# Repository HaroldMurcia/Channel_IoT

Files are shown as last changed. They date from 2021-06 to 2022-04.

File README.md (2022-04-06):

# Channel_IoT
<p align='left'>
    
    
</p>

# **Índice**   
- 1 [INSTALACION DE HERRAMIENTAS](#id1)
  - 1.1 [MPLABX](#id2)
  - 1.2 [Instalación de **MPLAB X** en Ubuntu](#id3)
  - 1.3 [Instalación del compilador XC8 en ubuntu ](#id4)
  - 1.4 [Instalación de MPLAB CODE CONFIGURATOR MCC ](#id5)
  - 1.5 [LoRa Development Suite](#id6)
- 2 [HARDWARE](#id7)
  - 2.1 [Documentos relacionados ](#id8) 
  - 2.2 [Requerimientos de hardware](#id9)
  - 2.3 [Enlaces de interés](#id10)
- 3 [Diseño de schematic y PCB en Eagle](#id11)
  - 3.1 [Estructura de la PCB](#id12)
  - 3.2 [PCB  Botton y Top](#id13)
  - 3.3 [Modelo PCB en 3D](#id14)
- 4 [Errores de diseño](#id36)
- 5 [Comandos modulo RN2903](#id15)
   - 5.1 [Comandos radio ](#id16)
     - 5.1.1 [Comandos para inicializar el radio **modulación LoRa**](#id17)
     - 5.1.2 [Comandos de transmisión](#id18)
     - 5.1.3 [Comandos de recepción](#id19) 
- 6 [Protocolo serial ](#id21)
  - 6.1 [Tablas de contenido del mensaje](#id22)
    - 5.1.1 [Cabecera del mensaje](#id23)
    - 5.1.2 [Tabla de familia](#id24)
    - 5.1.2 [Descripción tablas](#id25)
- 7 [Documentación de código](#id26)
-  6.1 [Versiones de software](#id27)
    - 7.1.1 [Programación en PIC18Lf45k50](#id28)
    - 7.1.2 [Programación en dsPIC30F4011](#id29)
    - 7.1.2 [Interfaz nodo maestro](#id30)
- 8 [Resultados](#id31)
  - 8.1 [Apertura de compuerta](#id32)
  - 8.2 [Distancia del sensor de ultrasonido](#id33)
  - 8.3 [Alimentación de la board](#id34)
  - 8.4 [Temperatura de la board](#id35)

# INSTALACION DE HERRAMIENTAS  
## MPLABX  
Este algoritmo se ha realizado en [Mplab x IDE](https://www.microchip.com/en-us/development-tools-tools-and-software/mplab-x-ide) Versión 5.50 en el compilador [XC8]( https://www.microchip.com/en-us/development-tools-tools-and-software/mplab-xc-compilers) versión 2.32. A su vez se usó el plugin MCC [MPLAB® Code Configurator]( https://www.microchip.com/en-us/development-tools-tools-and-software/embedded-software-center/mplab-code-configurator) el cual esta disponible para windows linux y mac, este ayuda a generar las librerías básicas del micro controlador, cabe aclarar que la familia dspic30 no tiene soporte en este plugin.

## Instalación de **MPLAB X** en Ubuntu  
Primero se verifica la arquitectura de sistema, para ello abrimos una terminal y ejecutamos el siguiente comando:
```
uname - m
```
uname -m

Se mira si la distribución de Linux tiene soporté de multi arquitectura en el caso de no tenerlo se debe instalar una librería especial
```
dpkg --print-foreign-architectures
```
arquitectura

Entonces aquí se observa que nos devuelve i386 lo que quiere decir que, si es multi arquitectura, ahora antes de seguir con el proceso se debe verificar que no haya actualizaciones del sistema 
```
sudo apt-get update
```
Ahora lo que se debe hacer es instalar las librerías para que **MPLAB**  sea compatible con instrucciones de procesador de 32bits
```
sudo apt-get install libc6:i386 libx11-6:i386 libxext6:i386 libstdc++6:i386 libexpat1:i386
```
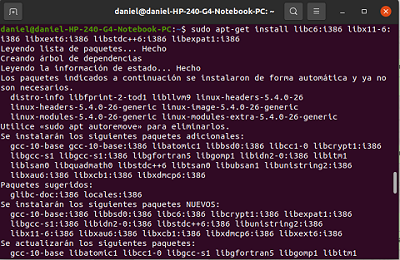
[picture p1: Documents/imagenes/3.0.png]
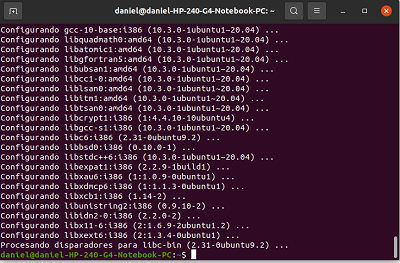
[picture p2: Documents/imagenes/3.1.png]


Ahora se busca la  página oficial de microchip para descargar [MPLAB X IDE]( https://www.microchip.com/en-us/development-tools-tools-and-software/mplab-x-ide) en la sección de **Downloads, Documentation and Other Resources**
Después de haber descargado el software, nos dirigimos a la carpeta en la que se descargo
```
cd descargas/
```
Para la instalación del software, se descomprime el archivo y se convierte el archivo descargado a ejecutable  
```
tar -xvf MPLABX-v5.50-linux-installer.tar
chmod u+x MPLABX-v5.50-linux-installer.sh
```
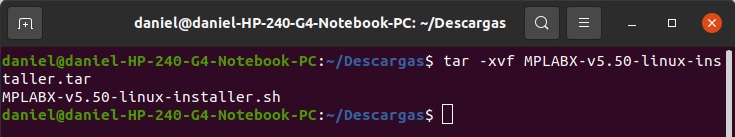
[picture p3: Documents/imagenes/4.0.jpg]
descomprime

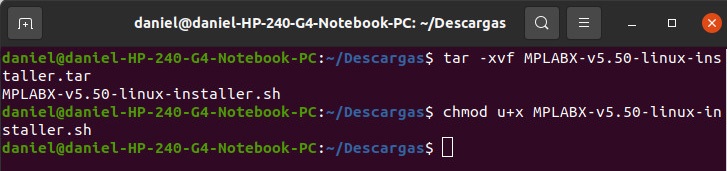
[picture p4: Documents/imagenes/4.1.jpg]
ejecutable


Ejecutar el instalador 
```
sudo ./MPLABX-v5.50-linux-installer.sh
```
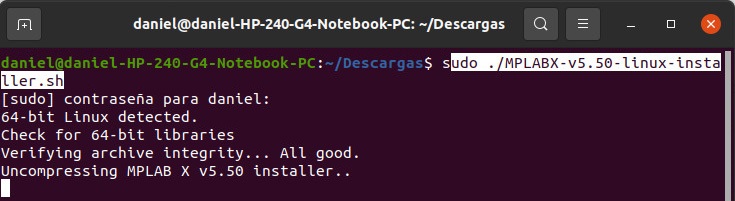
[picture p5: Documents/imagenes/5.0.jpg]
intalador


A continuación, se muestra las partes mas importantes del instalador 

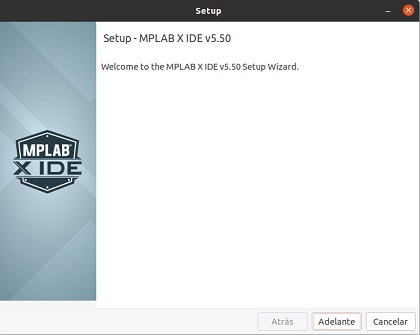
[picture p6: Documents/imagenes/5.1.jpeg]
ventana1

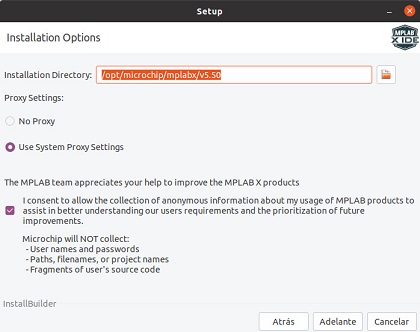
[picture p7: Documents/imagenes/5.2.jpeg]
ventana2

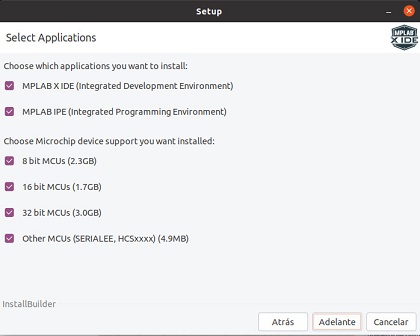
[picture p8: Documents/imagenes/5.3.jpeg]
ventana3


Al final de la instalación se debe reiniciar el PC para completar el proceso de instalación 

## Instalación del compilador XC8 en ubuntu  
Ahora es necesario instalar el compilador para el microcontrolador que desee trabajar 8bits,16bits y 32bits [MPLAB XC]( https://www.microchip.com/en-us/development-tools-tools-and-software/mplab-xc-compilers) sección **Downloads, Documentation and Other Resources** y **compiler dowloads**

Después de haber descargado la aplicación, vamos a la carpeta en la que lo guardamos y lo volvemos un ejecutable y lo ejecutamos 
```
chmod u+x xc8-v2.32-full-install-linux-x64-installer.run
sudo ./xc8-v2.32-full-install-linux-x64-installer.run
```
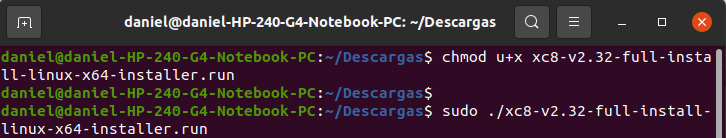
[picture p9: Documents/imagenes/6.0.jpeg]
xc8


Se deja todo por defecto y next

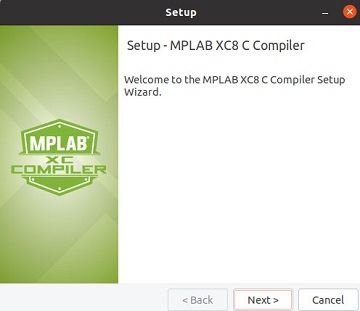
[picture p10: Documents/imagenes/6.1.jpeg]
ventana4


Al final de la instalación se debe reiniciar el PC para completar el proceso de instalación

## Instalación de MPLAB CODE CONFIGURATOR MCC  
Cabe aclarar que MCC es solamente compatible con la ultima versión de MPLAB X y esta disponible para todos los sistemas operativos. Además el procesos se realizo en ubuntu, sin embargo es el mismo proceso para Windows y MAC os.

MCC es un plugin que permite configurar algunos microcontroladores de una manera rápida y sencilla, ya que este genera una interfaz en la que se puede configurar una serie de parámetros, utilizar algunas librerías y este genera código de la librería según los parámetros estipulados  para comenzar a trabajar en el proyecto.

**Nota: MCC no es compatible con la familia DSPIC30**

* Abrir la aplicación de MPLAB X IDE
* Tools
* plugins
* Available Plugins
* Y buscamos MPLAB Code Configurator 
* Pulsar en install

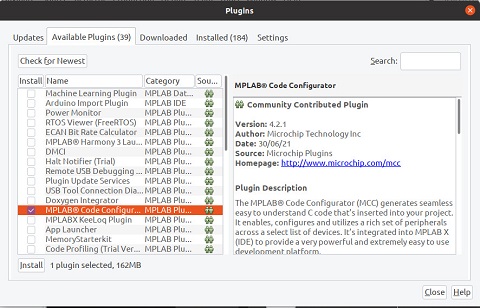
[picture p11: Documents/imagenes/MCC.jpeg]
MCC
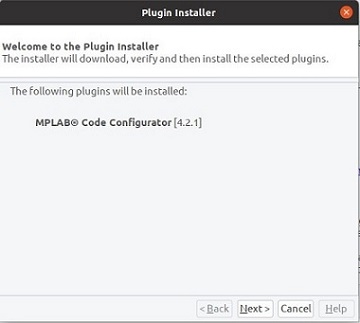
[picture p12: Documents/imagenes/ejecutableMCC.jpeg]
EJECUTABLEMCC
  
 
Al final de la instalación se escoge reset now, y se reinicia MPLAB X después aparecerá de la siguiente manera, “si no se ha creado ningún proyecto”

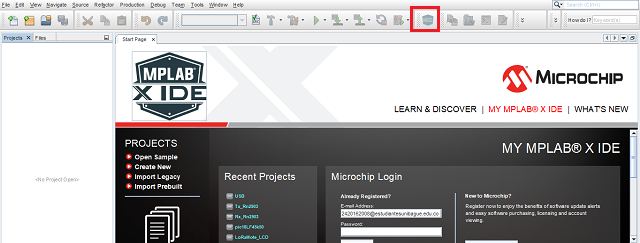
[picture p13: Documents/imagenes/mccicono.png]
MCCicono


## LoRa Development Suite  
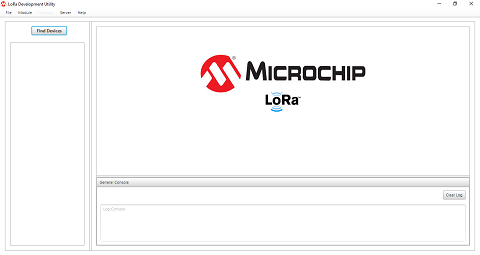
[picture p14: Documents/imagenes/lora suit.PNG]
lora suit


Es una interfaz grafica que permite la configuración de los diferentes comandos que implementa modulo RN2903 y RN2483, de esta manera el usuario aprenda como debe enviar los datos de manera serial sin muchas complicaciones, **cabe aclarar que esta interfaz no es estrictamente necesaria para configurar el módulo RN2903,ya que es una guía, de igual forma, los comandos se pueden enviar mediarte el UART programndo el  microcontrolador** para más información  mirar la guía de comandos del [módulo RN2903]( https://ww1.microchip.com/downloads/en/DeviceDoc/RN2903%20LoRa%20Technology%20Module%20Command%20Reference%20User%20Guide-40001811B.pdf)

### instalación
Esta aplicación esta disponible para todos los sistemas operativos y se puede encontrar en la [pagina oficial de microchip]( https://www.microchip.com/wwwproducts/en/RN2903), en el apartado de **Documents**, **software libreires/firmware** se encuentran las aplicaciones, solo basta con abrir la aplicación darle next y **mirar la ruta de la carpeta en la que se va instalar ya que se debe ir a buscar la ampliación a ese  directorio** esto es para el caso de Windows. Ir al siguiente enlace en caso de [Linux
]( https://www.gaggl.com/2018/04/microchip-lorawan-development-utility-on-ubuntu/)

### RN2903 ACTUALIZAR FIREWARE
El siguiente video tiene como objetivo explicar la forma de actualizar el firmware del modulo RN2903 de la tarjeta LoRa Mote, dado el caso de que se allá borrado el firmware del módulo RN2903 [Video en youtube](https://youtu.be/kyjtmIkalMk)

# HARDWARE  
Este repositorio tiene como objetivo mostrar  los elementos que componen el sistema y su configuración en con construcción de esta, es decir la asignación de pines o conexiones de los dispositivos entre si.

## Documentos relacionados  
* [Configuración o asignación de pines](https://docs.google.com/spreadsheets/d/19cve4B_YzyOGqIv9DEK3eCqArvopMfsAZXm61Hay0jQ/edit?usp=sharing)
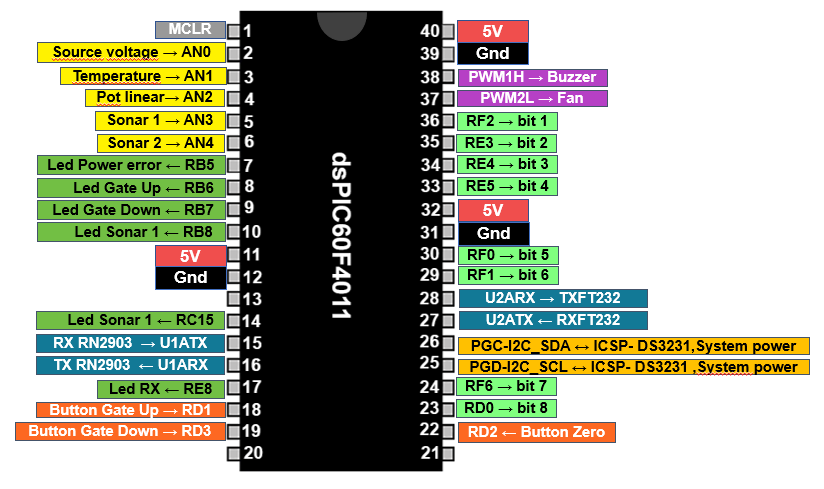
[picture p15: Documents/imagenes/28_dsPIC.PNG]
Resumen de pindes

* [Google Drive](https://drive.google.com/drive/folders/19VFRMTp_xo8fuAuP7UYOIrlyNO1dNOWd?usp=sharing)
* [Diagrama de bloques](https://drive.google.com/file/d/1_osPgyQmuKj5nIkt5gdU3hPU3BZLeOLT/view?usp=sharing)
* [Schematic](https://github.com/HaroldMurcia/Channel_IoT/blob/master/Eagle/schematic.pdf)

## Requerimientos de hardware  
A continuación se muestran los componentes principales que encabezan el sistema, los demás dispositivos se encuentran en [Datasheet]( https://github.com/HaroldMurcia/Channel_IoT/tree/master/Hardware/Datasheet)
* [MaxSonar](https://co.mouser.com/ProductDetail/DFRobot/SEN0272?qs=T8HDo%252BTk69VWj8BEbH%252BU3Q%3D%3D)
* [LoRa Mote](https://www.microchip.com/Developmenttools/ProductDetails/dm164139)
* [Microchip RN2903](https://www.microchip.com/wwwproducts/en/RN2903)
* [Dspic30f4011](https://www.microchip.com/wwwproducts/en/dsPIC30F4011)

## Enlaces de interés  
* [Platformio](https://platformio.org/)
* [RAdioHead](https://www.airspayce.com/mikem/arduino/RadioHead/)

# Diseño de schematic y PCB en Eagle  
[Cotización de los componentes](https://docs.google.com/spreadsheets/d/1AnpxCE8uhZ4Mzhw6TfTGnhGRriO4N8LUufEemXK9A1I/edit#gid=807096094) En este link se entra la cotización de los diferentes componentes usados en la PCB exceptuando la tarjeta LoRa mote, Dspic, Tblocks y buzzer, dicha cotización se realizo para armar 3 tarjetas, mas adelante se describe  de manera superficial la función del componente.

## Estructura de la  PCB  
En el siguiente [enlace](https://docs.google.com/spreadsheets/d/1AnpxCE8uhZ4Mzhw6TfTGnhGRriO4N8LUufEemXK9A1I/edit#gid=1786186541) se encontrarán la distribución de los pines del DSpic para realizar las diferentes conexiones, este archivo contiene el número del pin, así como el label del esquemático de Eagle su tipo de puerto, es decir si es ADC, Digital etc.

La siguiente imagen muestra la distribución de cada uno de los componentes usados para la Pcb, estos componentes tienen su letra y numero correspondiente o identificador del componente, además de su valor si este lo requiere, cada  uno de los componentes se situó de manera estratégica, de tal manera que sea fácil soldar y acceder a este; de igual forma cada elemento esta lo más cerca posible a la conexión con otros dispositivos con los que se interconecta con el fin de tener la menor resistencia posible en la pista que los interconecta. 
La siguiente [tabla](https://docs.google.com/spreadsheets/d/1AnpxCE8uhZ4Mzhw6TfTGnhGRriO4N8LUufEemXK9A1I/edit#gid=1117524344) muestra la descripción mas detallada de cada elemento de la PCB.

Como se puede evidenciar la pcb diseñada es doble capa y cuenta con dos tamaños de anchura, cada uno de estos tamaños fueron calculados por medio de la norma IPS2221, estos cálculos se hicieron por medio de una calculadora que ofrece [Digikey]( https://www.digikey.com/es/resources/conversion-calculators/conversion-calculator-pcb-trace-width) para ello se busco en el datasheet de cada unos de los componentes las corrientes nominales, el consumo de cada uno de los componentes es bajo y en ancho de la pista es muy pequeño, por tanto por requerimientos mínimos que exigen algunas empresas para la fabricación de las pcb para  cada pista debe ser de 0.2mm, para este diseño se tomo un valor por arriba que es de 0.254mm, por otra parte para el calculo de las pistas de potencia se sumo la corriente nominal de todos los componentes, esto se hizo buscado el peor de los casos, lo cual hace suponer que todos los componentes están encendidos en el mismo momento. La corriente total fue alrededor de 1.3A, por tanto el anchor de la pista es de 0.55mm, sin embargo se sobre dimensiono un poco ya que algunos dispositivos pueden tener picos de corriente que muchas veces  no se especifica en el datasheet por tanto el ancho es de 1.016mm, por ultimo para realizar el cálculo se escogió una temperatura ambiente de 25°C y el aumento de temperatura de 30°C el espesor de 1oz/ft^2. 
[Tabla de cosumo y calculos de ruteo](https://docs.google.com/spreadsheets/d/1AnpxCE8uhZ4Mzhw6TfTGnhGRriO4N8LUufEemXK9A1I/edit#gid=618312286)

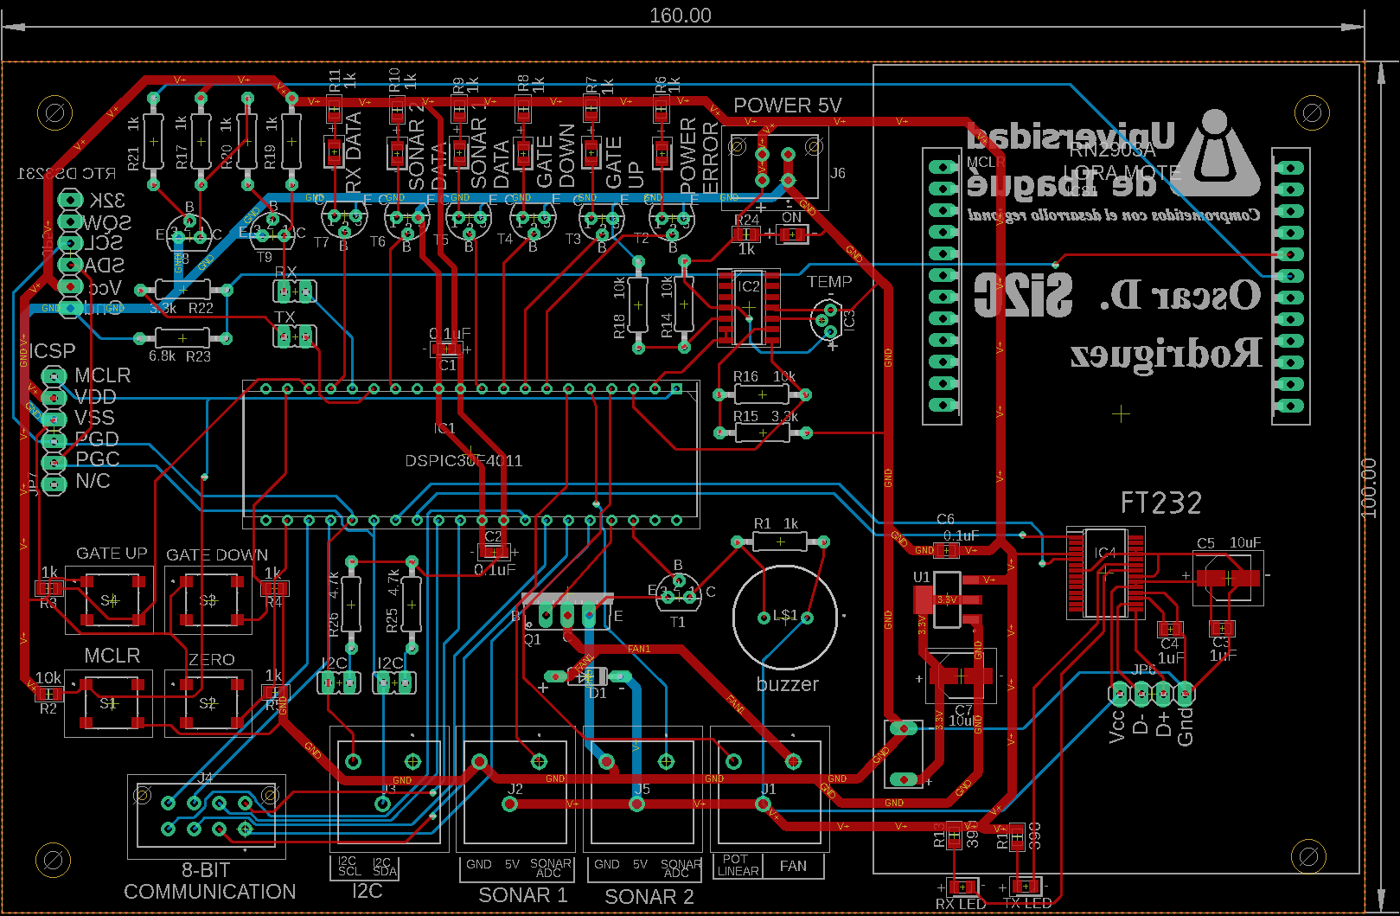
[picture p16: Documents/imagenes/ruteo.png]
PCB ruteo

## PCB  Caras Botton Y Top  

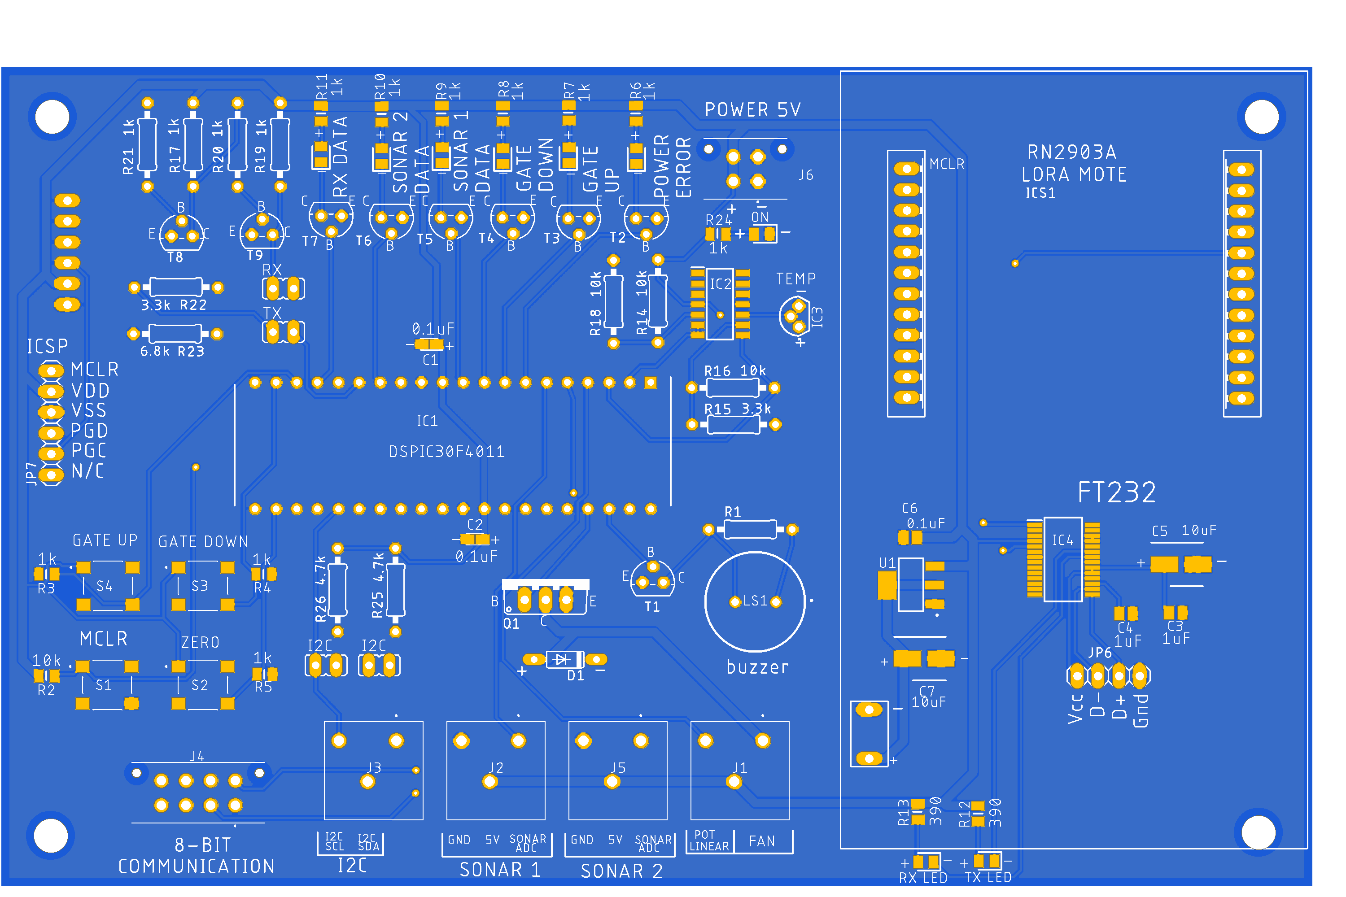
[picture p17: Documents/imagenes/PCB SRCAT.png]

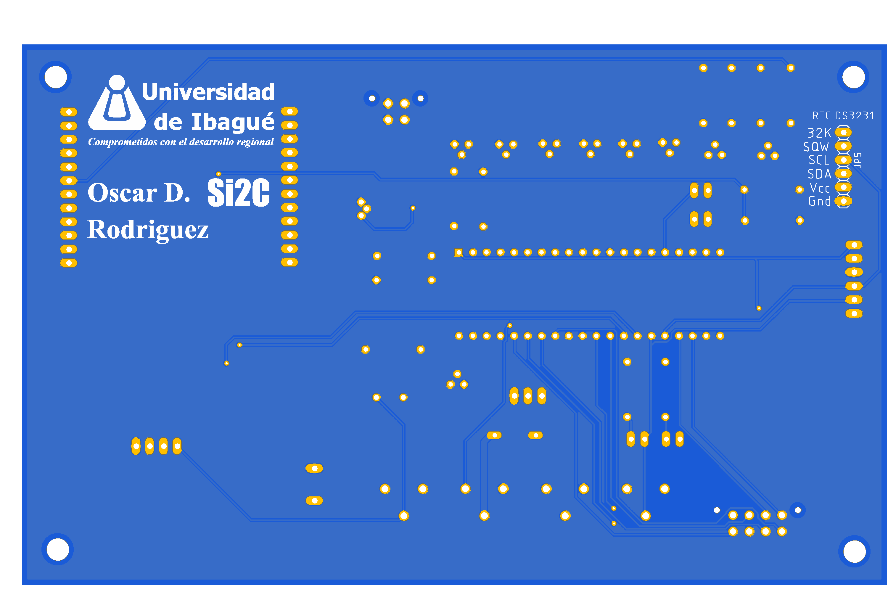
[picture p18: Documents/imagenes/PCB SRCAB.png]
PCB BOTTOM


## Modelo PCB en 3D 
La Pcb cuenta con diferentes componentes, la alimentación cuenta con un conector molex de 4 pines, el cual tiene una sola forma de conectar, por otra parte los indicadores visuales y audibles son indicadores del estado en que se encuentran el sistema, por otra parte el microcontrolador es que se encargara de procesar los diferentes sensores, procesamiento de datos y envió de datos al LoRa, por otra parte los sensores se leen mediante ADC, el bloque de comunicación de sistema de potencia se usa para comunicar un sistema de potencia que se encarga de abrir o cerrar la compuerta, los botones de calibración sirven para abrir o cerrar la compuerta calibrar la altura de sensores sonar, por último se dejó un puerto para programar el microcontrolador con un pickit mediante ICSP.
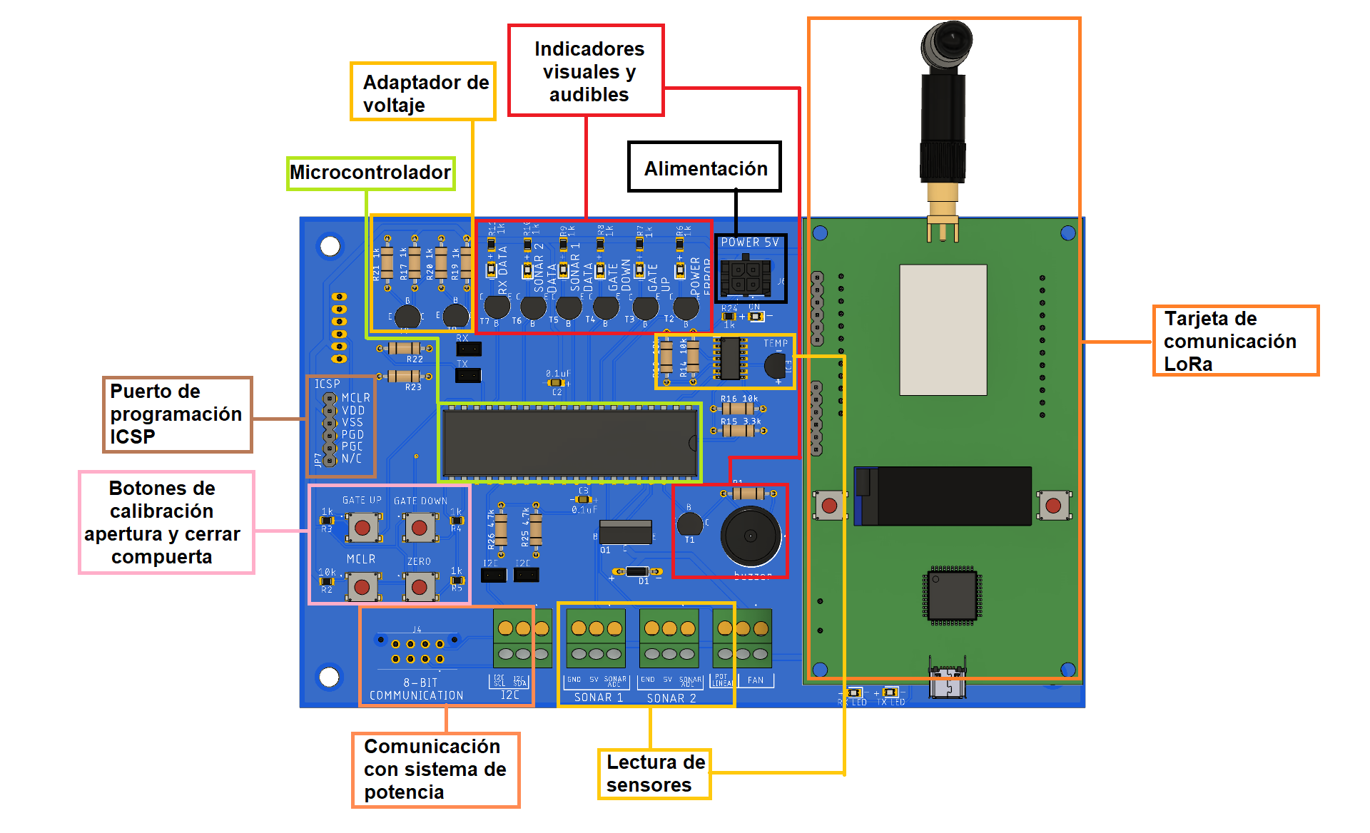
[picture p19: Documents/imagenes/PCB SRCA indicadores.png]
PCB SRCA indicadores


[Modelo en fusion360](https://a360.co/3zkWzcB)
Clave: 159753
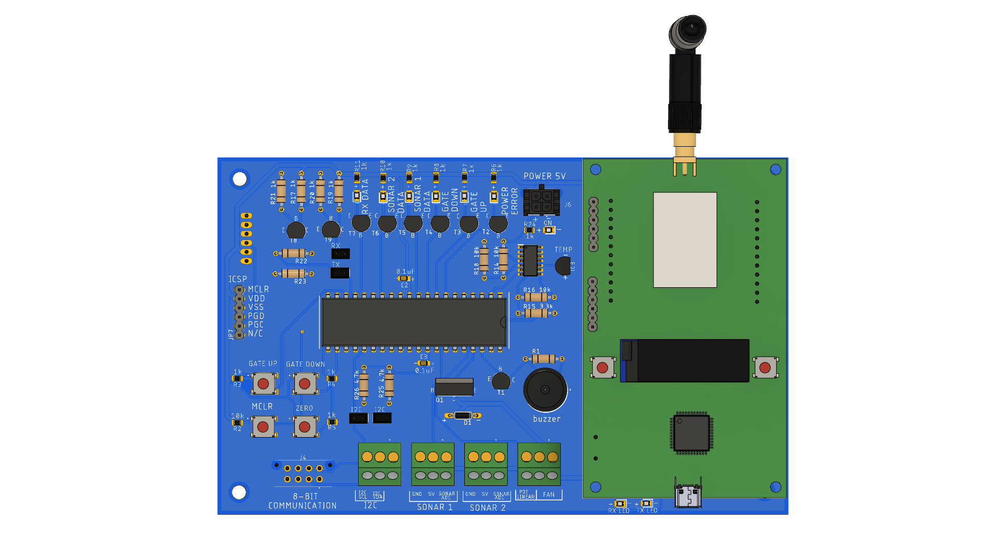
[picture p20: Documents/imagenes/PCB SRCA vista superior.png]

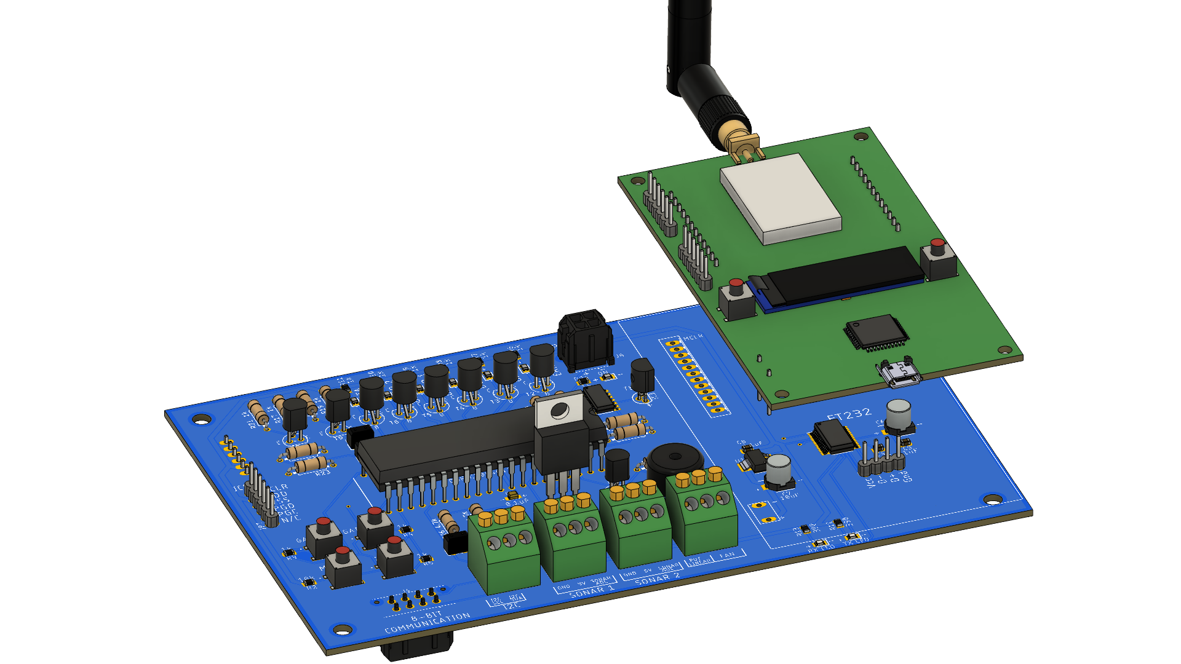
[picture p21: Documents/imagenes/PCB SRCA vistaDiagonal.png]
PCB TOP DIAGOANL

# Errores de diseño 
- El primer error se encuentra en la parte de los pulsadores, las pistas para soldar cada pulsador son muy cortas, por tanto se deben dejar con mayor longitud a la actual, con el fin de que el pulsador se pueda soldar con mayor facilidad.
- cuando se construyeron las librerías del ADC, en la hoja de datos de la familia dsPIC30f se especifica que se deben conectar los pines 40 y 39 a la alimentación para la referencia del ADC, no obstante, la hoja de datos del dsPIC30f4011 especificaba que los pines eran usados para colocar un voltaje entre 2.7 y 5V, con lo anterior, se colocaron dos cables entre la base del dsPIC y el MCU, para poder leer las señales análogicas provenientes de los sensores.

# Comandos modulo RN2903
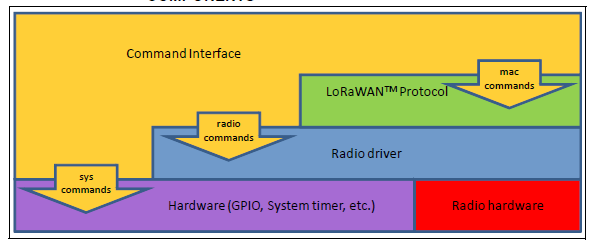
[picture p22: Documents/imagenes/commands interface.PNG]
commands interface


El modulo RN2903 tiene una gran cantidad de comandos, sin embargo solo se deben usar una cabecera para la comunicación ya sea **mac o radio**, en esta sección se implementaron los comandos radio, estos facilitan la comunicación entre dos módulos RN2903.

Por otra parte, los comandos en general se deben enviar con la misma cantidad de espacios que especifica la hoja de datos, a su vez al final de cada comando se de enviar retorno de carro **CR** y salto de línea **LF** .

## Comandos radio

### Comandos para inicializar el radio **modulación LoRa**

1. El siguiente comando permite cambiar el método de modulación utilizado por el módulo.
Además, la modificación del modo de funcionamiento no afecta los parámetros, variables o
registros previamente configurados. Así mismo, el comando es muy simple ya que solamente
decide si es LoRa o FSK. En este documento se trabaja los comandos relacionados con LoRa.
```http
  radio set mod <mode>
```
| Parametro | Comando  | Parametro |Description parametro | Tipo de respuesta |
| :--- | :--- | :--- |:--- | :---|
| `radio set` |  `mod` | `<mode>` |**String**. lora o fsk |  ok o invalid_param  |

`Ejemplo` 
```http
  radio set mod lora\r\n
```
2. El siguiente comando determina la potencia de salida del transceptor. La cual se puede
ajustar por encima del límite especificado, este ajuste de potencia permite compensar algunas
pérdidas en el cable o línea de transmisión en dBm. El valor máximo que puede alcanzar es
de 17 dBm a 20 dBm
```http
  radio set pwr <pwrOut>
```
| Parametro | Comando  | Parametro |Description parametro | Tipo de respuesta |
| :--- | :--- | :--- |:--- | :---|
| `radio set` |  `pwr` | `<pwrOut>`  |**Decimal**. de 2 hasta 20 |  ok o invalid_param  |

`Ejemplo` 
```http
   radio set pwr 3\r\n 
```
3. Este comando establece el ancho de banda de radio para el funcionamiento de LoRa,
ambos dispositivos deben tener el mismo ancho de banda, puesto que, ambos dispositivos se
comportan como transmisor y receptor 
```http
  radio set bw <bandWidth>
```
| Parametro | Comando  | Parametro |Description parametro | Tipo de respuesta |
| :--- | :--- | :--- |:--- | :---|
| `radio set` |  `bw` | `<bandWidth>`  |**Decimal**. puede ser de 125,250,500 en KHz |  ok o invalid_param  |

`Ejemplo` 
```http
   radio set bw 250\r\n 
```
4. El comando crc permite activar o desactivar la detección de errores, CRC Cyclic Redun-
dancy Check este comando se usa para detectar errores o cambios accidentales en datos
sin procesar. Por tanto, si el detector de errores encuentra irregularidades en los mensajes
automáticamente los eliminará del sistema
```http
  radio set crc < crcHeader >
```
| Parametro | Comando  | Parametro |Description parametro | Tipo de respuesta |
| :--- | :--- | :--- |:--- | :---|
| `radio set` |  `crc` | `<crcHeader>`  |**String**. puede ser on o off |  ok o invalid_param  |

`Ejemplo` 
```http
   radio set crc on\r\n
```
5. El siguiente comando permite configurar la tasa de codificación de errores. Esto significa
que cada 4 bits útiles se codificarán con 5, 6, 7 u 8 bits transmitidos según su valor.
```http
  radio set cr <codingRate>
```
| Parametro | Comando  | Parametro |Description parametro | Tipo de respuesta |
| :--- | :--- | :--- |:--- | :---|
| `radio set` |  `cr` | `<codingRate>`  |**String**. puede ser 4/5,4/6, 4/7, 4/8.|  ok o invalid_param  |

`Ejemplo` 
```http
   radio set cr 4/5\r\n
``` 
6. El siguiente comando permite configurar la frecuencia de operación del transmisor y
receptor. Cabe añadir que el transmisor y receptor deben estar sintonizados a la misma
frecuencia, si no se cumple, no habrá comunicación entre los dispositivos.
```http
  radio set freq <frequency>
```
| Parametro | Comando  | Parametro |Description parametro | Tipo de respuesta |
| :--- | :--- | :--- |:--- | :---|
| `radio set` |  `freq` | `<frequency>`  |**Decimal**. puede ser 902000000 a 928000000 en Hz|  ok o invalid_param  |

`Ejemplo` 
```http
   radio set freq 923300000\r\n
``` 
7. El siguiente comando permite   configurar la inversión IQ.
```http
  radio set iqi <iqInvert>
```
| Parametro | Comando  | Parametro |Description parametro | Tipo de respuesta |
| :--- | :--- | :--- |:--- | :---|
| `radio set` |  `iqi` | `<iqInvert>`  |**String**. puede ser on o off |  ok o invalid_param  |

`Ejemplo` 
```http
  radio set iqi off\r\n
``` 
8. El watchDog actualiza la duración del tiempo de espera (en milisegundos) del
temporizador de vigilancia aplicado al módulo. Cuando esta función está habilitada, el reloj
de vigilancia se iniciará para cada transceptor que recibe o transmite. El reloj de Watchdog
se detiene mientras una actividad está en curso. Si el parámetro de la recepción es continuo
WDT debe ser 0.
```http
  radio set wdt <watchDog>
```
| Parametro | Comando  | Parametro |Description parametro | Tipo de respuesta |
| :--- | :--- | :--- |:--- | :---|
| `radio set` |  `wdt` | `<watchDog>`  |**Decimal**. puede ser 0 a 4294967295 en milisegundos. |  ok o invalid_param  |

`Ejemplo` 
```http
  radio set wdt 15000\r\n
``` 
9. El parámetro sf permite configurar el factor de dispersión ortogonal FS, esta instrucción es
muy importante, ya que, la configuración ayuda a aumentar o disminuir el rango de alcance
que puede ser entre 5 km en zonas urbanas y 15 km en zona rural. Sin embargo,
la velocidad de transmisión de datos se ve afectada por el valor que tome SF lo que hace
que disminuya o aumente la velocidad de transmisión, es decir, que FS a mayor rango es
inversamente proporcional a la velocidad de transmisión de datos en kb/s..
```http
  radio set sf <spreadingFactor>
```
| Parametro | Comando  | Parametro |Description parametro | Tipo de respuesta |
| :--- | :--- | :--- |:--- | :---|
| `radio set` |  `sf` | `<spreadingFactor>`  |**String**. puede ser sf7, sf8, sf9, sf10, sf11 o sf12. |  ok o invalid_param  |

`Ejemplo` 
```http
  radio set sf SF12\r\n 
``` 
10. El parámetro sync configura la palabra de sincrónica para la comunicación, esta palabra
para la modulación LoRa es de 1 byte y se usa para sincronizar una transmisión de datos
indicando el final de la información del encabezado y el inicio de los datos, la cual debe ser
igual en el dispositivo que reciba la información.
```http
  radio set sync <syncWord>
```
| Parametro | Comando  | Parametro |Description parametro | Tipo de respuesta |
| :--- | :--- | :--- |:--- | :---|
| `radio set` |  `sync` | `<syncWord>`  |**Hexadecimal**. tamaño de un Byte|  ok o invalid_param  |

`Ejemplo` 
```http
  radio set sync 34\r\n 
``` 
### COMANDOS DE TRANSMISIÓN  

1. El siguiente comando pausa la funcionalidad de la pila LoRaWAN para permitir la configuración del transceptor (radio).  
Se debe llamar antes de hacer una transmisión o recepción.
```http
  mac pause
```
| Cabecera | Comando  | Description parametro | Tipo de respuesta |
| :--- | :--- | :--- | :---|
| `mac` |  `pause` |**Decimal**. 0 – 4294967295 en milisegundos |  ok o invalid_param  |

`Ejemplo` 
```http
  mac pause\r\n
```
2. El siguiente comando permite   configurar La transmisión de datos simples  
```http
  radio tx <data>
```
| Cabecera | Comando  | Parametro |Description parametro | Tipo de respuesta |
| :--- | :--- | :--- |:--- | :---|
| `radio` |  `tx` | `<data>`  |**Hexadecimal**. de 0 hasta 255  Bytes |  ok,invalid_param, busy,radio_tx_ok o radio_err  |

`Ejemplo` 
```http
   radio tx 1\r\n     
```
3. El siguiente comando reanuda la funcionalidad de la pila LoRaWAN para continuar con la funcionalidad normal después de haber sido pausado.  
Se debe realizar cuando se termina de hacer una transmisión o recepción  
```http
  mac resume
```
| Cabecera | Comando  | Description parametro | Tipo de respuesta |
| :--- | :--- | :--- | :---|
| `mac` |  `pause` |**Decimal**. 0 – 4294967295 en milisegundos |  ok o invalid_param  |

`Ejemplo` 
```http
  mac resume\r\n
```
### Comandos de Recepción   

1. El siguiente comando pausa la funcionalidad de la pila LoRaWAN para permitir la configuración del transceptor (radio).  
Se debe llamar antes de hacer una transmisión o recepción.
```http
  mac pause
```
| Cabecera | Comando  | Description parametro | Tipo de respuesta |
| :--- | :--- | :--- | :---|
| `mac` |  `pause` |**Decimal**. 0 – 4294967295 en milisegundos |  ok o invalid_param  |

`Ejemplo` 
```http
  mac pause\r\n
```
2. El siguiente comando permite   configurar La transmisión de datos simples  
```http
  radio rx <rxWindowSize>
```
| Cabecera | Comando  | Parametro |Description parametro | Tipo de respuesta |
| :--- | :--- | :--- |:--- | :---|
| `radio` |  `rx` | `<rxWindowSize>`  |**Decimal**. de 0 hasta 65525 milisegundos, 0 recepción continua |  ok,invalid_param, busy,radio_tx_ok o radio_err  |

`Ejemplo` 
```http
   radio rx 0\r\n     
```
3. El siguiente comando reanuda la funcionalidad de la pila LoRaWAN para continuar con la funcionalidad normal después de haber sido pausado.  
Se debe realizar cuando se termina de hacer una transmisión o recepción  
```http
  mac resume
```
| Cabecera | Comando  | Description parametro | Tipo de respuesta |
| :--- | :--- | :--- | :---|
| `mac` |  `pause` |**Decimal**. 0 – 4294967295 en milisegundos |  ok o invalid_param  |

`Ejemplo` 
```http
  mac resume\r\n
```

# Protocolo serial
Este es un protocolo que se implementa para hacer una comunicación entre maestro y esclavo, de manera que se pueda reconocer que se esta enviando, como llega el mensaje y que datos son los que se están enviado, a continuación, se explica como esta conformado 
## Tablas de contenido del mensaje
### Cabecera del mensaje
| star msg | ID1  | ID2 |Type of Reading | Data |end smg|
| :--- | :--- | :--- |:--- | :---| :---|
|`radio_rx `|`ID master`|`ID slave`|`Msg family`|`Data info`|`\r\n`|

### TABLA DE FAMILIA   
| ID1|ID2|Type Command  | Description |
| :--- | :--- |:--- | :---|
|`ID master` **Decimal de 0-255**|`ID slave` **Decimal de 0-255**|`0`|`Reserved`|
|`ID master` **Decimal de 0-255**|`ID slave` **Decimal de 0-255**|`1`|`Sonar H	`|
|`ID master` **Decimal de 0-255**|`ID slave` **Decimal de 0-255**|`2`|`sonar L	`|
|`ID master` **Decimal de 0-255**|`ID slave` **Decimal de 0-255**|`3`|`Temp	`|
|`ID master` **Decimal de 0-255**|`ID slave` **Decimal de 0-255**|`4`|`Power	`|
|`ID master` **Decimal de 0-255**|`ID slave` **Decimal de 0-255**|`5`|`Fecha hora	`|
|`ID master` **Decimal de 0-255**|`ID slave` **Decimal de 0-255**|`6`|`%Apertura compuerta	`|
|`ID master` **Decimal de 0-255**|`ID slave` **Decimal de 0-255**|`7`|`confirmacion	` falta definirlo|

|Type Command  | Data | Meaning |
| :--- | :--- |:---- |
|`1`|`0`| reserved	 | 
|`1`|`1-4999mm`| **sonar_on_H**| 

|Type Command  | Data | Meaning |
| :--- | :--- |:---- |
|`2`|`0`| reserved	 | 
|`2`|`1-4999mm`| **sonar_on_L**|

|Type Command  | Data | Meaning |
| :--- | :--- |:---- |
|`3`|`0`| reserved	 | 
|`3`|`1-60°c`| **read_temp**| 

|Type Command  | Data | Meaning |
| :--- | :--- |:---- |
|`4`|`0`| reserved	 | 
|`4`|`4-5V`| **power_on**| 

|Type Command  | Data | Meaning |
| :--- | :--- |:---- |
|`5`|`0`| reserved	 | 
|`5`|`hora/mes/año`| **send_datatime**| 

|Type Command  | Data | Meaning |
| :--- | :--- |:---- |
|`6`|`0`| reserved	 | 
|`6`|`%(0-100)`| **Enable_motor **| 

|Type Command  | Data | Meaning |
| :--- | :--- |:---- |
|`7`|`0`| reserved	 | 
|`7`|`1`| **send_data **| 
|`7`|`2`| **get_data  **| 

### Descripción tablas   

Como se mostró anteriormente el protocolo cuenta con diferentes tablas, de esta manera mostrar a gran escala como se conforma protocolo. Para empezar, el protocolo tiene una palabra de inicio ` star msg ` la cual viene definida por el módulo RN2903 que es: ` radio_rx` con esta se identifica donde comienza el mensaje. Las siguientes palabras del mensaje son los identificadores de las tarjetas  ` ID1 = ID master`, ` ID2 = ID slave`, estos identificadores pueden tener un valor en decimal entre  0 – 255 cada tarjeta debe tener un numero único, de tal forma que cuando se envié la información no haya más de un dispositivo recibiendo algo que no debe, estos identificadores sirven para saber con quién se está haciendo la comunicación  ` ID1 = ID master` y de donde proviene la información ` ID2 = ID slave`, además estos identificadores se usan para saber si se deben procesar la información o no ya que  hay varia tarjetas sintonizadas a la misma frecuencia.

La siguiente palabra clave del mensaje es tipo de comando `Type Command ` y este es un numero especifico, este se especifica en la **tabla de familia** en esta se muestra que significa cada valor, por otra parte, este dato le dice al que recibe el mensaje que tipo de lectura se ha enviado en el mensaje. Por ultimo las dos palabras que termina el mensaje son: datos y fin del mensaje `Data` `end smg` respectivamente. `Data` corresponde al valor de lectura de las mediciones o datos específicos que se estén enviado y `end smg` corresponde al final del mensaje, el cual esta definido por el modulo RN2903 y corresponde al retorno de carro CR y salto de línea LN \r\n 

# Documentación de código
La carpeta src contiene 4 diferentes capetas en las que se muestran diferentes códigos de manera simple a la mas compleja el manejo del dispositivo RN2903 usando una [comunicación simple]( https://github.com/HaroldMurcia/Channel_IoT/tree/master/src/Comunicacion%20basica%20MOTE%20a%20MOTE), usando una [comunicación avanzada]( https://github.com/HaroldMurcia/Channel_IoT/tree/master/src/Comunicacion%20avanzada%20Mote%20a%20Mote) usando una estructura de mensaje y por último la integración de sistema embebido construido [Nodo esclavo]( https://github.com/HaroldMurcia/Channel_IoT/tree/master/src/Nodo%20esclavo/SlaveDSpic.X). En la carpeta [InterfazNodoMaster]( https://github.com/HaroldMurcia/Channel_IoT/tree/master/src/InterfazNodoMaster) se encuentra la interfaz de nodo maestro.
## versiones de software
### Programación en PIC18Lf45k50
```http
   MPLAB X 5.45v
   XC8 compiler 2.25v
```
### Programación en dsPIC30F4011
```http
   MPLAB X 5.45v
   XC16 compiler 1.7v
```
### Interfaz nodo maestro
```http
   Python 3.9.7v
   serial 3.5v
   tkinter 8.5v
   threadign 3.8v
```
# Resultados
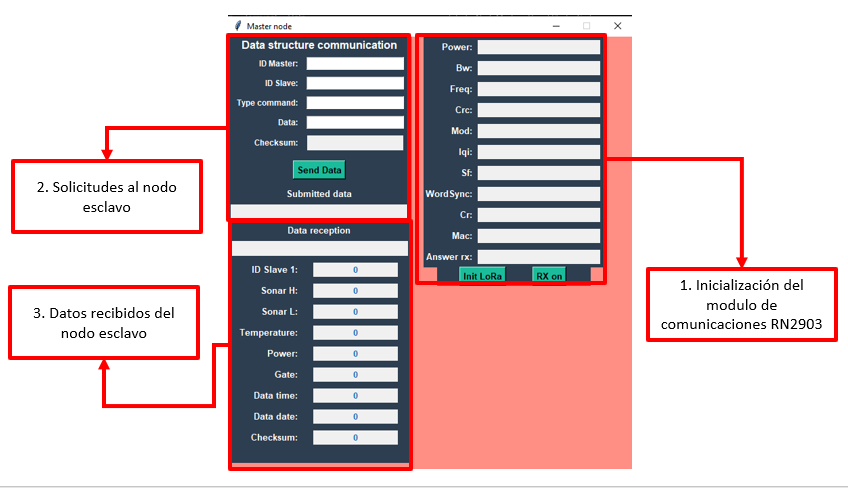
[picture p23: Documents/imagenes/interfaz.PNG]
interfaz
A continuación, se muestra la interfaz usada para la comunicación con el nodo maestro y además una serie datos representados gráficamente que fueron recolectadas en una ventana de 24 horas. 
## Apertura de compuerta
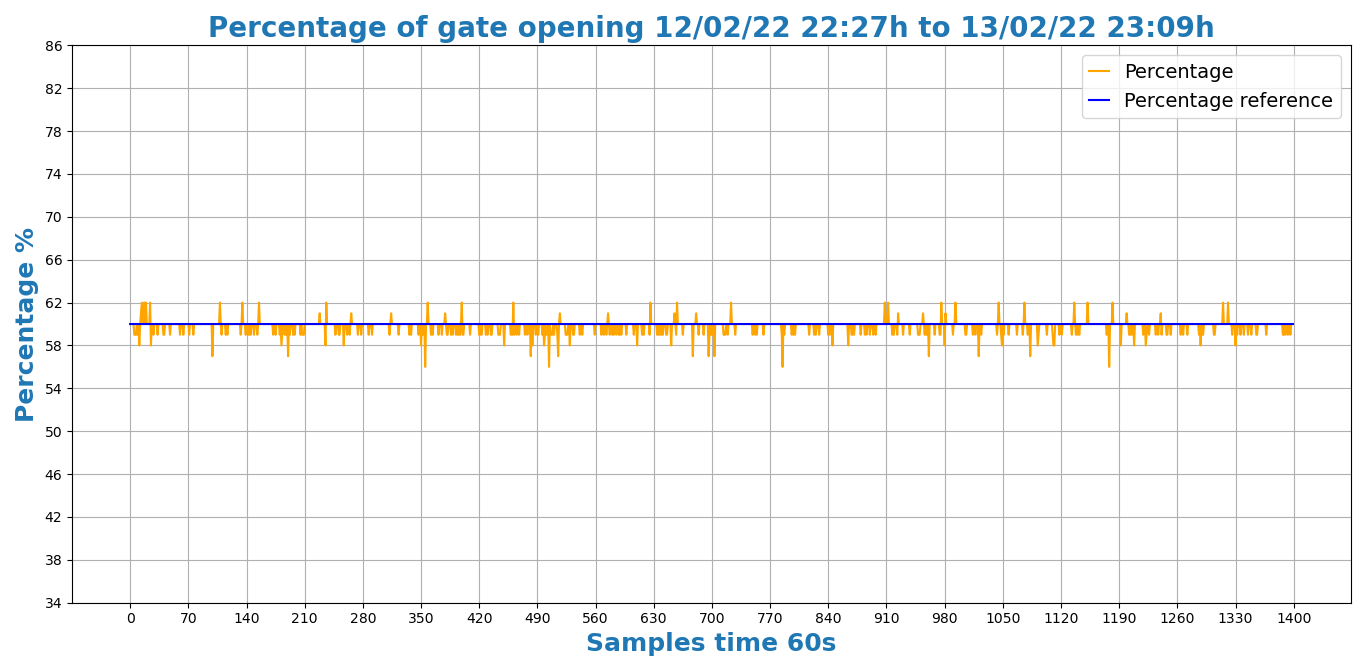
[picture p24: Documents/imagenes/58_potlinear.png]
Potecimetro

## Distancia del sensor de ultrasonido
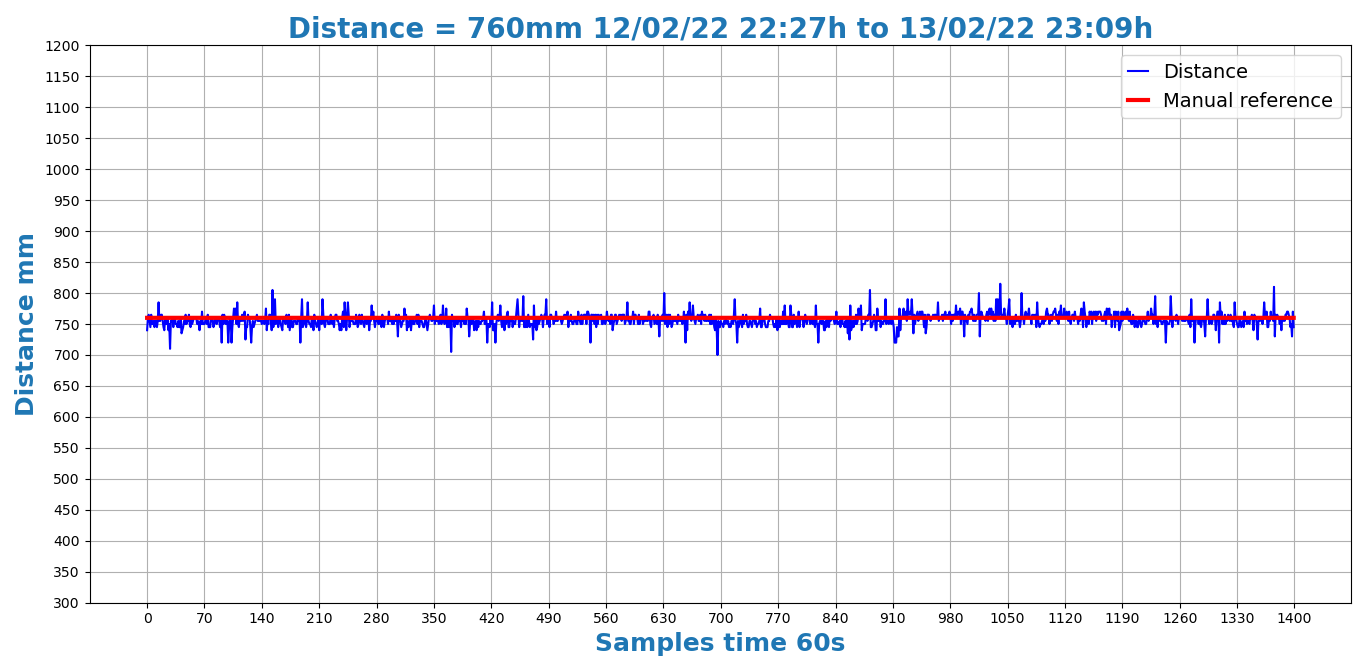
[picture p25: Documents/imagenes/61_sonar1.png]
ultrasonido

## Alimentación de la board
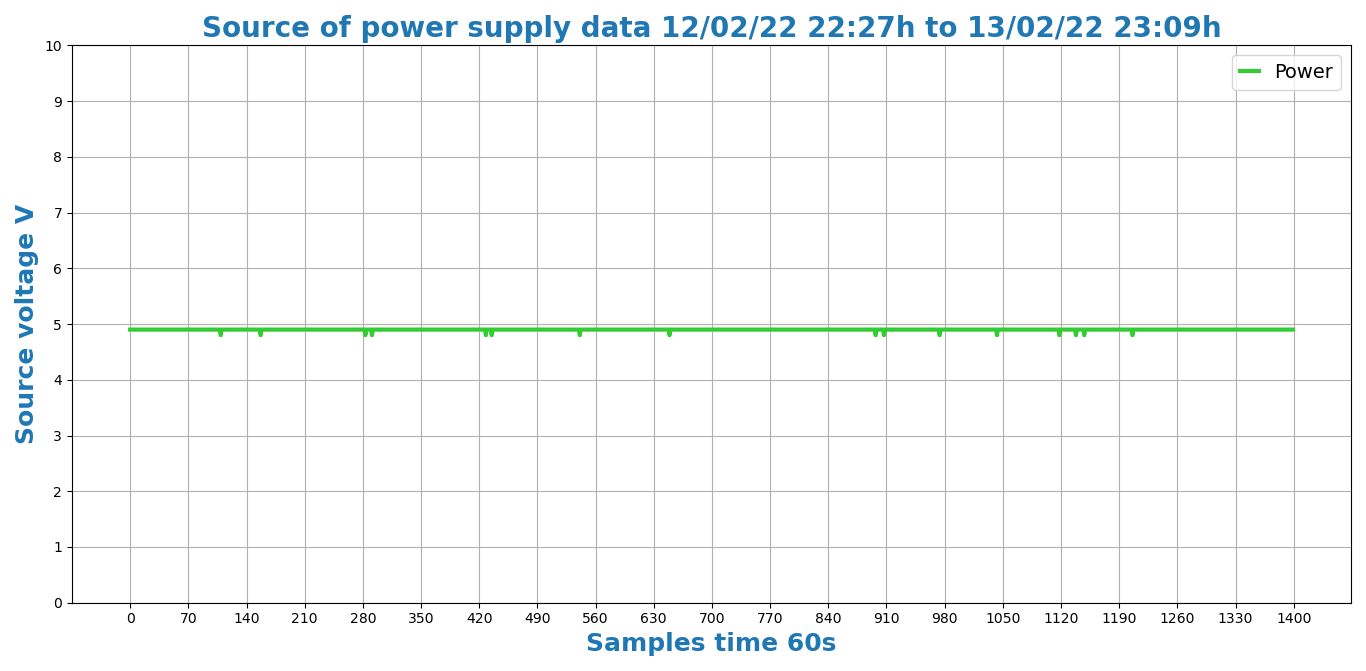
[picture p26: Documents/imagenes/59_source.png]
alimentancion

## Temperatura de la board
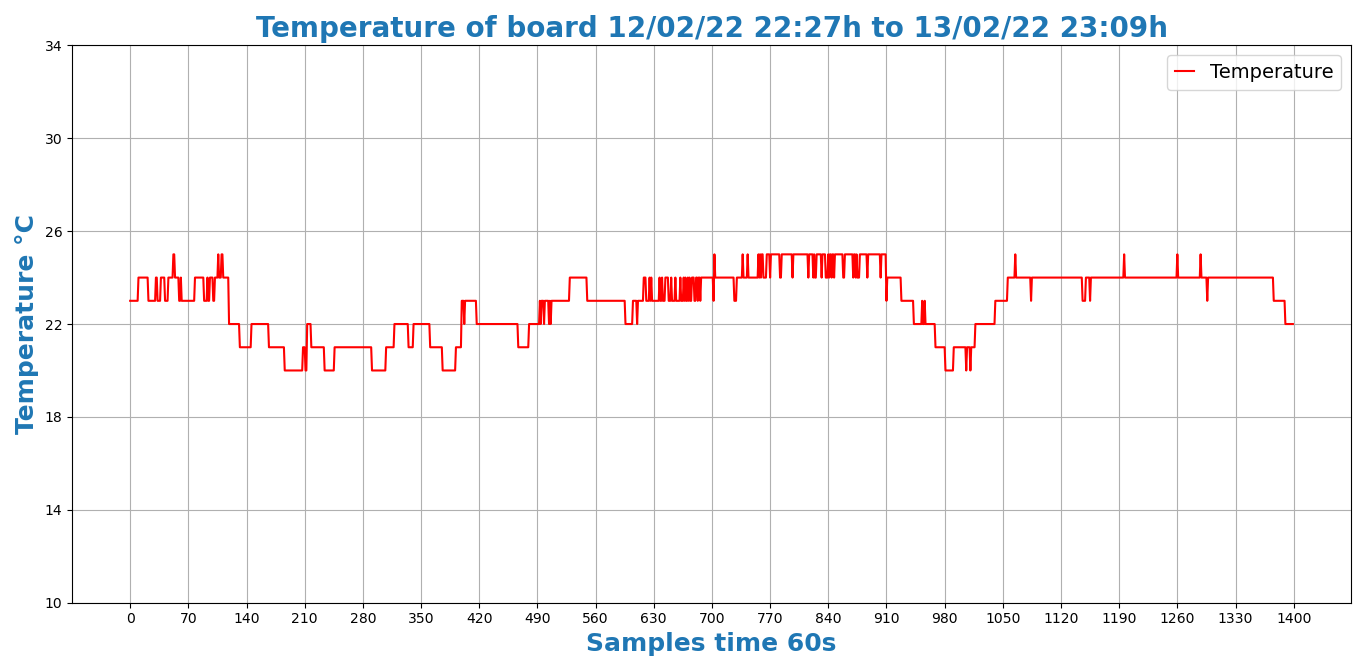
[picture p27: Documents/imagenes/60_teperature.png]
temperatura


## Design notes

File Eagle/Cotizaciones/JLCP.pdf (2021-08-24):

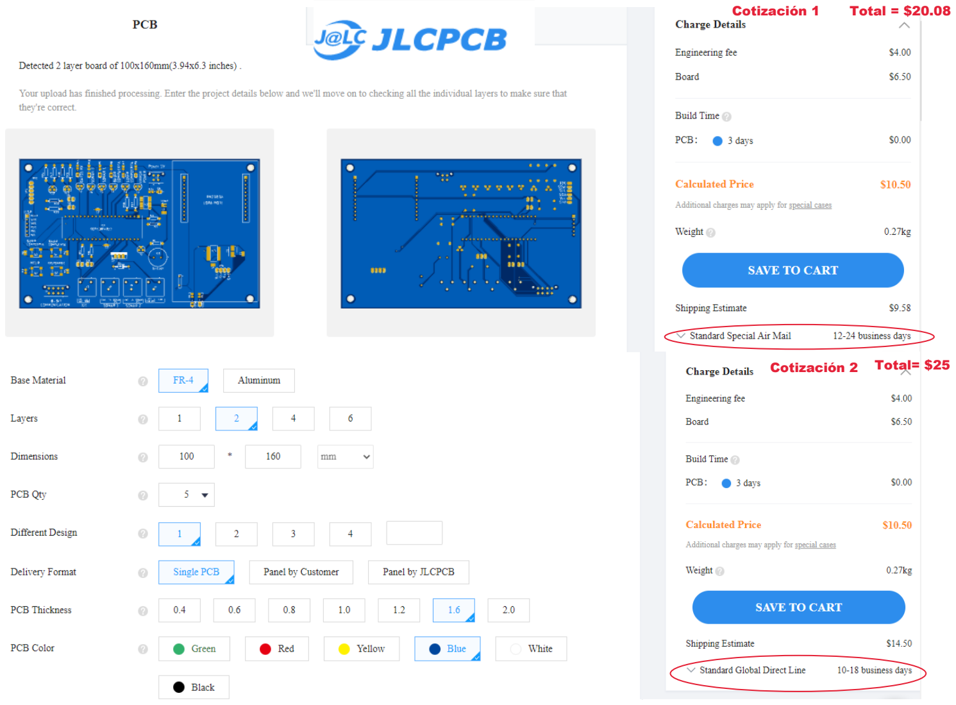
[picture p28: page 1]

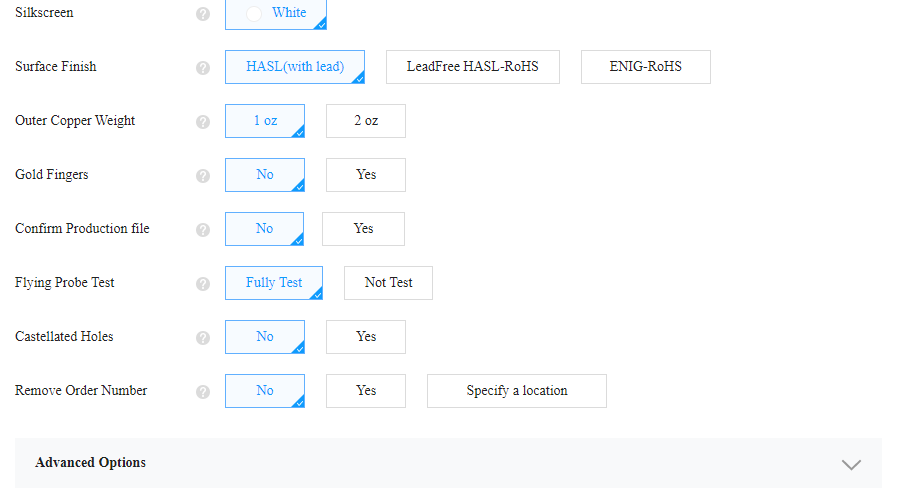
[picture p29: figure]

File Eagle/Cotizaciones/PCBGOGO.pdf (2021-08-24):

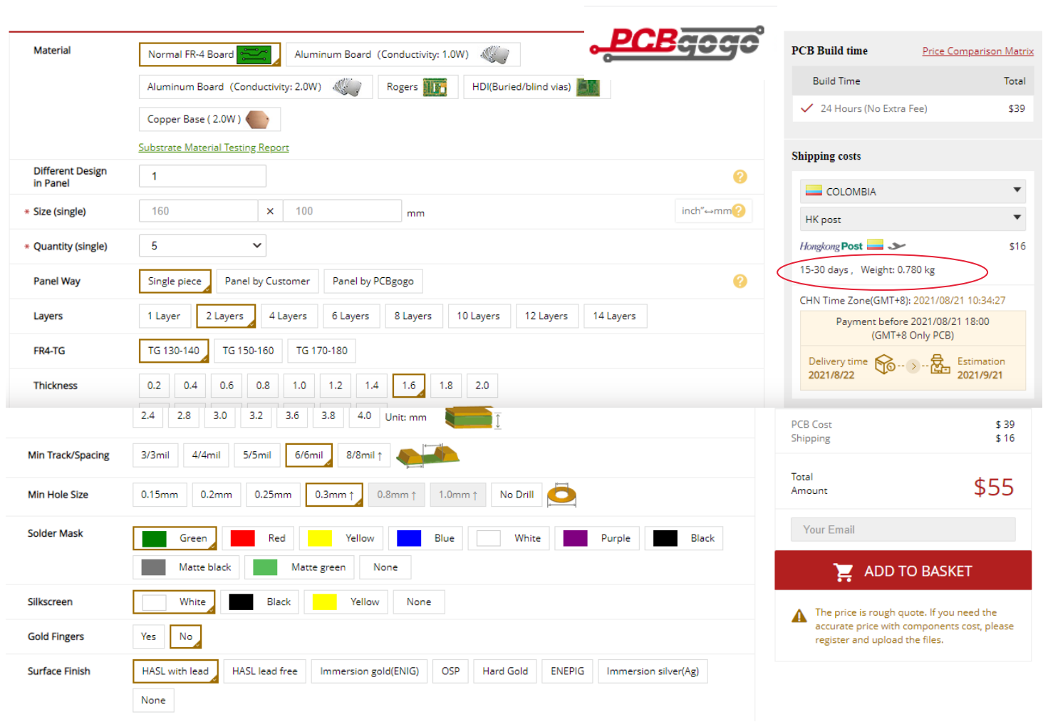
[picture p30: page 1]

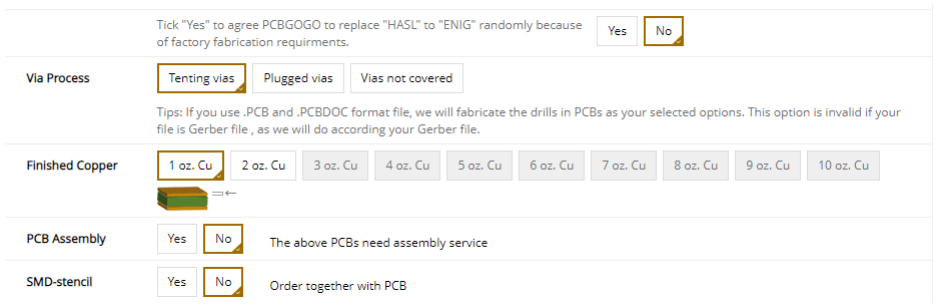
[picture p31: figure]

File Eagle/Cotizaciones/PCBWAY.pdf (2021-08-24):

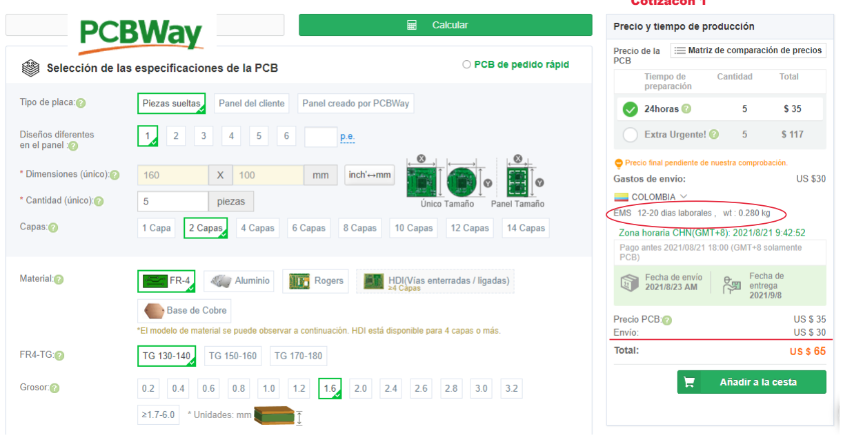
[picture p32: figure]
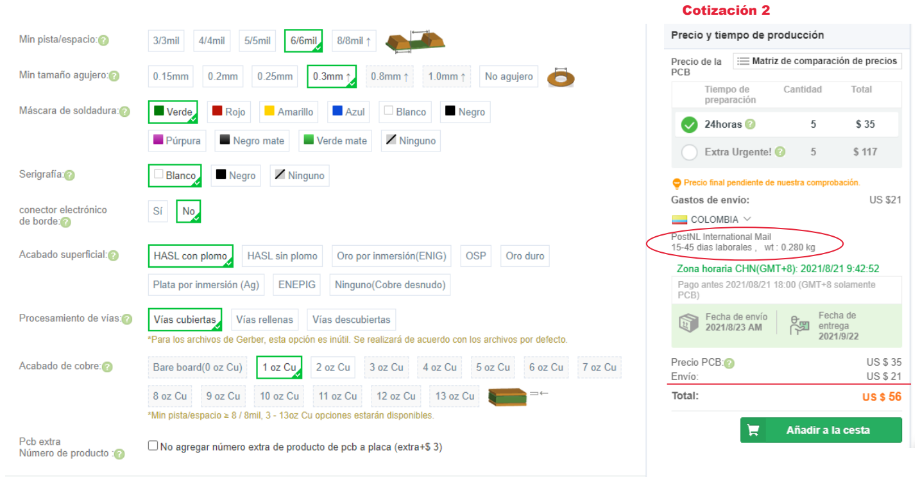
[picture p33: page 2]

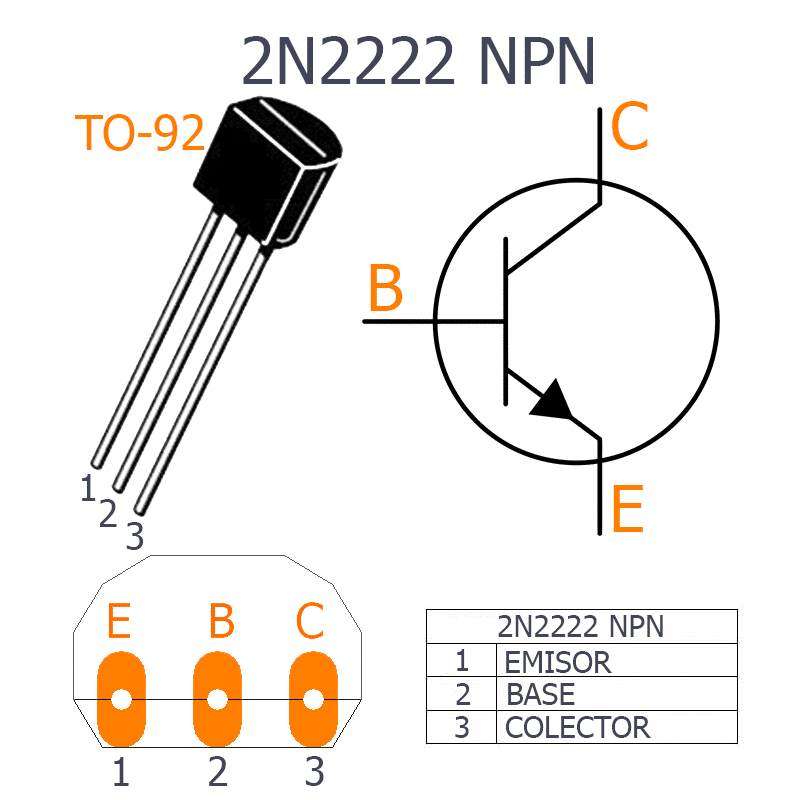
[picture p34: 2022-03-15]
Hardware/Datasheet/2N2222-NPN.png

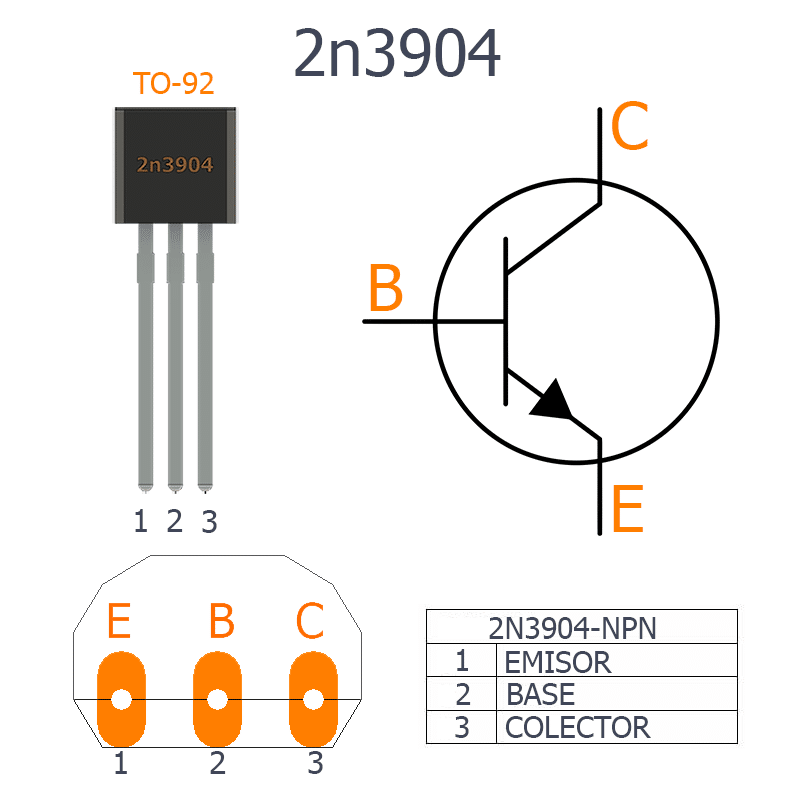
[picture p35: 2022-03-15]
Hardware/Datasheet/2N3904-B-1.png

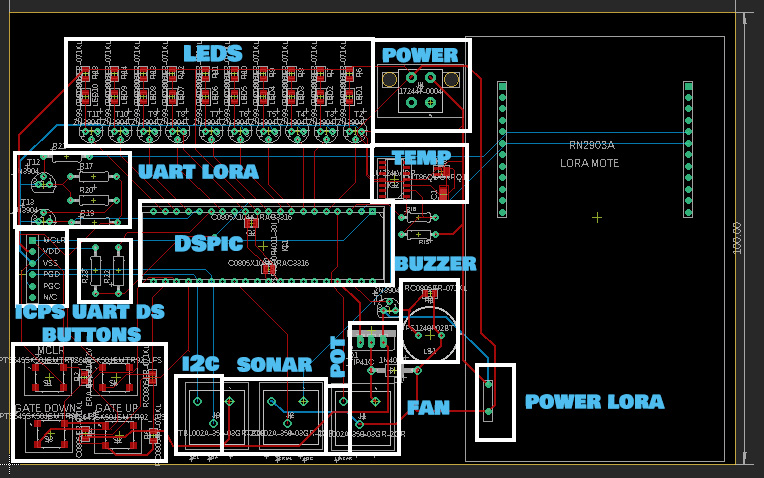
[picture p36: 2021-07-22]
Documents/imagenes/RUTEO.jpg

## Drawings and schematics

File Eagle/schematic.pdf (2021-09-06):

6/09/2021 4:46 p. m. C:\Users\ASUS\Documents\EAGLE\projects\PCB SRCA\PCB SRCA.sch (Sheet: 1/3) | SpiceOrder 1 SpiceOrder 2 1k | 1k | 1k 10k

# GND GND

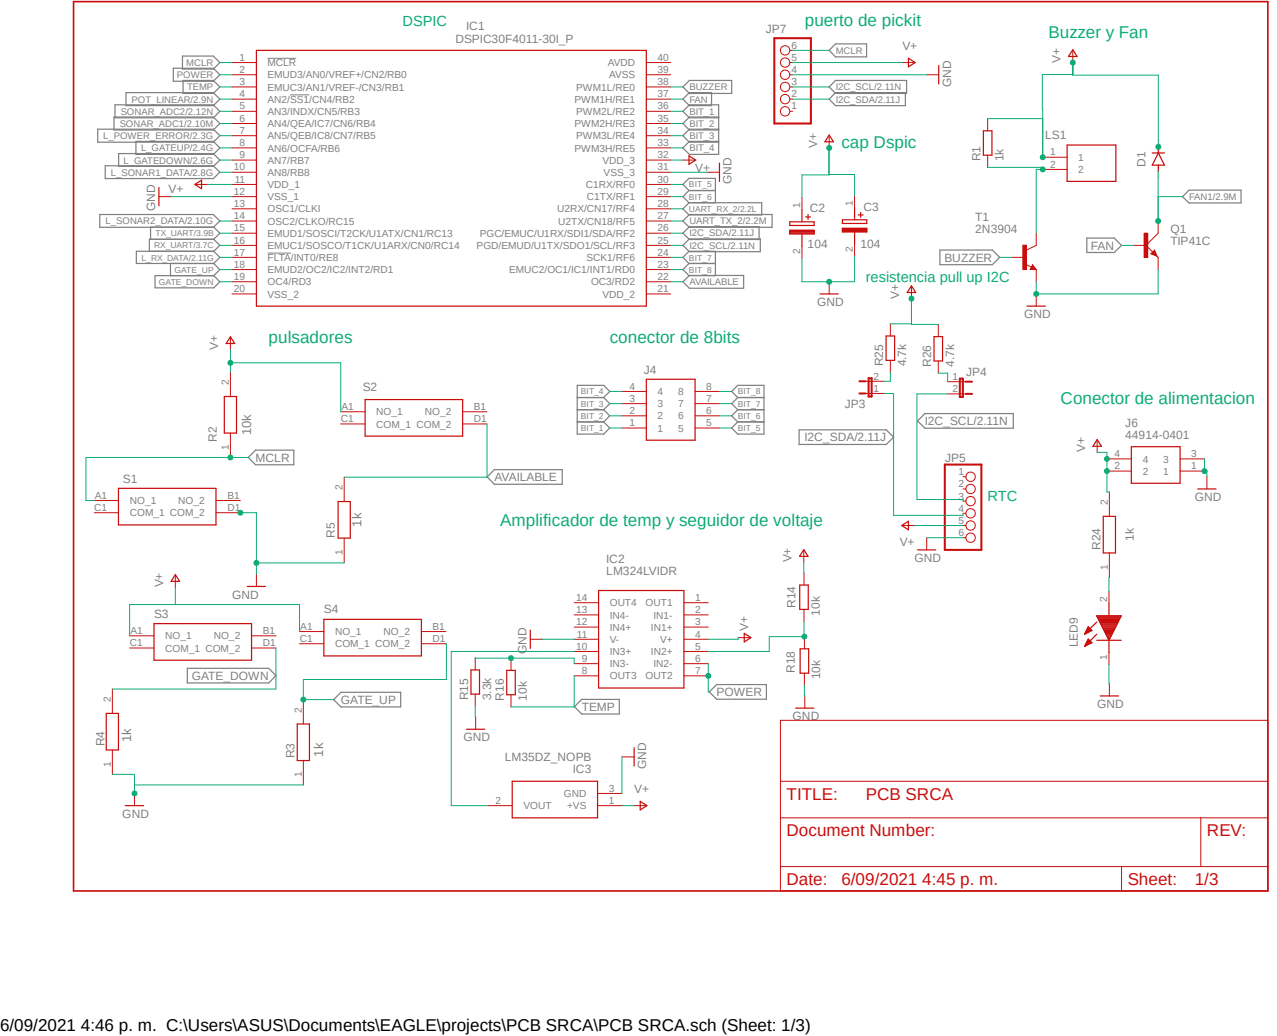
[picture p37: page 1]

SONAR_ADC2/2.12N | BIT_1
SONAR_ADC1/2.10M | BIT_2

L_SONAR2_DATA/2.10G | UART_TX_2/2.2M

TX_UART/3.9B | I2C_SDA/2.11J

Amplificador de temp y seguidor de voltaje

Document Number: | REV:

Date: 6/09/2021 4:45 p. m. | Sheet: 1/3

6/09/2021 4:46 p. m. C:\Users\ASUS\Documents\EAGLE\projects\PCB SRCA\PCB SRCA.sch (Sheet: 2/3) ³⁹⁰ | 390 1uF | 10uF | 1uF | 1K 1K 1K | 1K | 1K | 1K

## LEDS

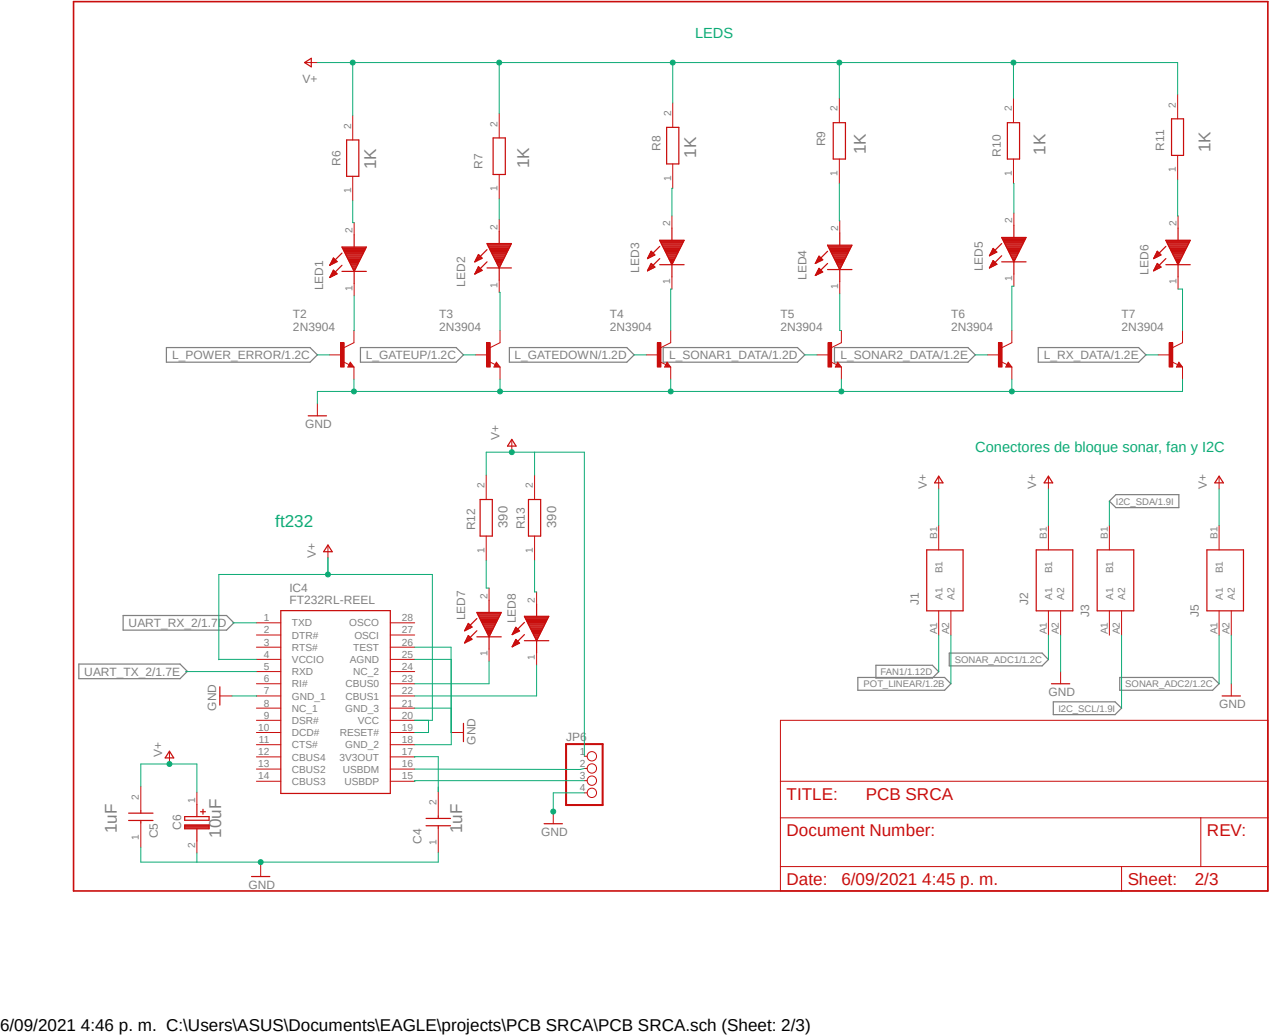
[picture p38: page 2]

Conectores de bloque sonar, fan y I2C

Document Number: | REV:

Date: 6/09/2021 4:45 p. m. | Sheet: 2/3

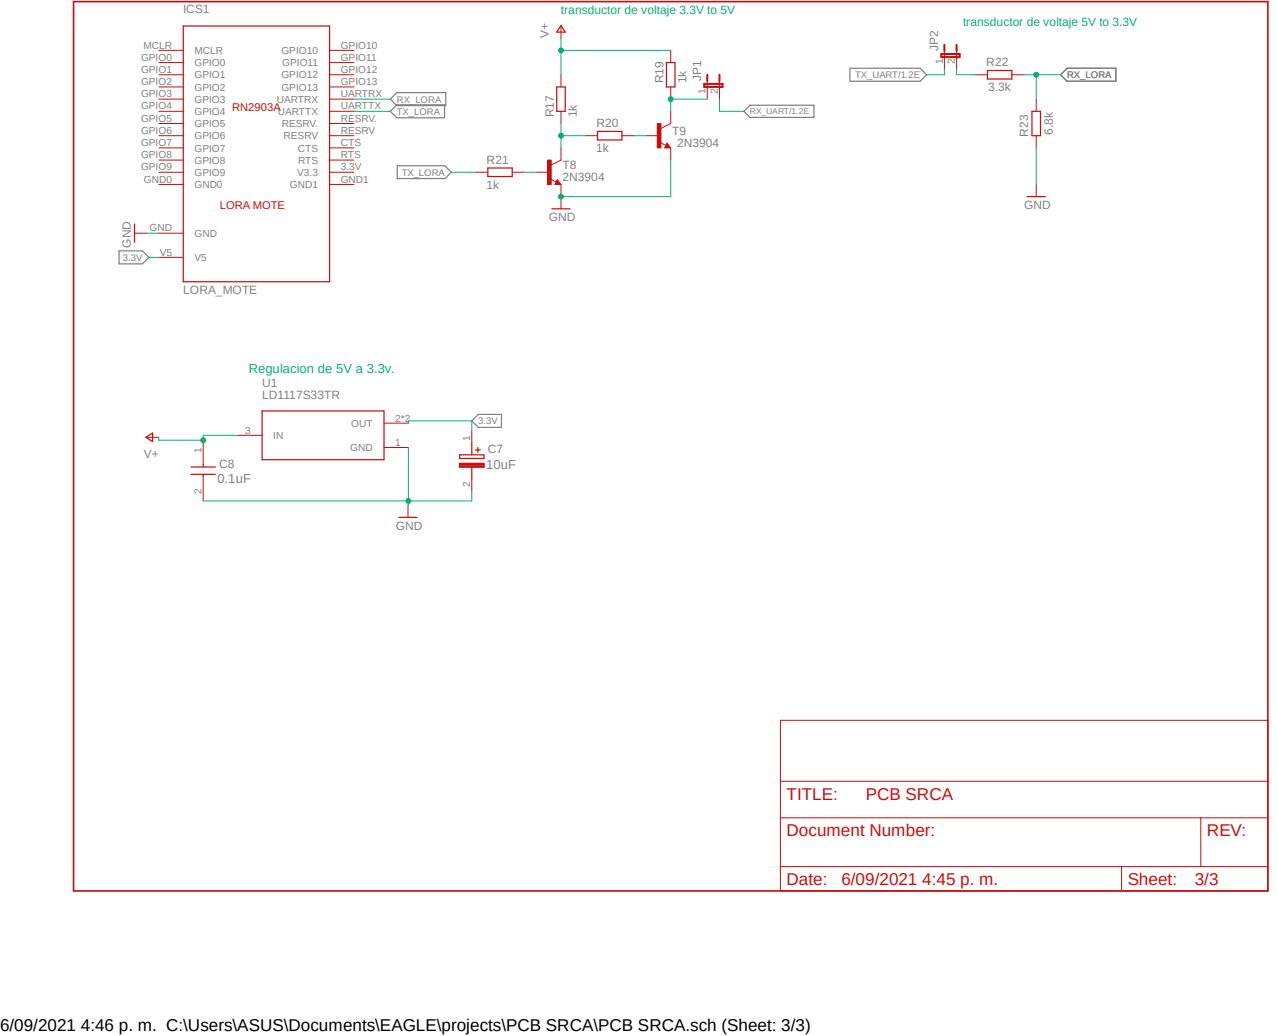
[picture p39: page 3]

transductor de voltaje 3.3V to 5V

transductor de voltaje 5V to 3.3V

Document Number: | REV:

Date: 6/09/2021 4:45 p. m. | Sheet: 3/3

6/09/2021 4:46 p. m. C:\Users\ASUS\Documents\EAGLE\projects\PCB SRCA\PCB SRCA.sch (Sheet: 3/3)

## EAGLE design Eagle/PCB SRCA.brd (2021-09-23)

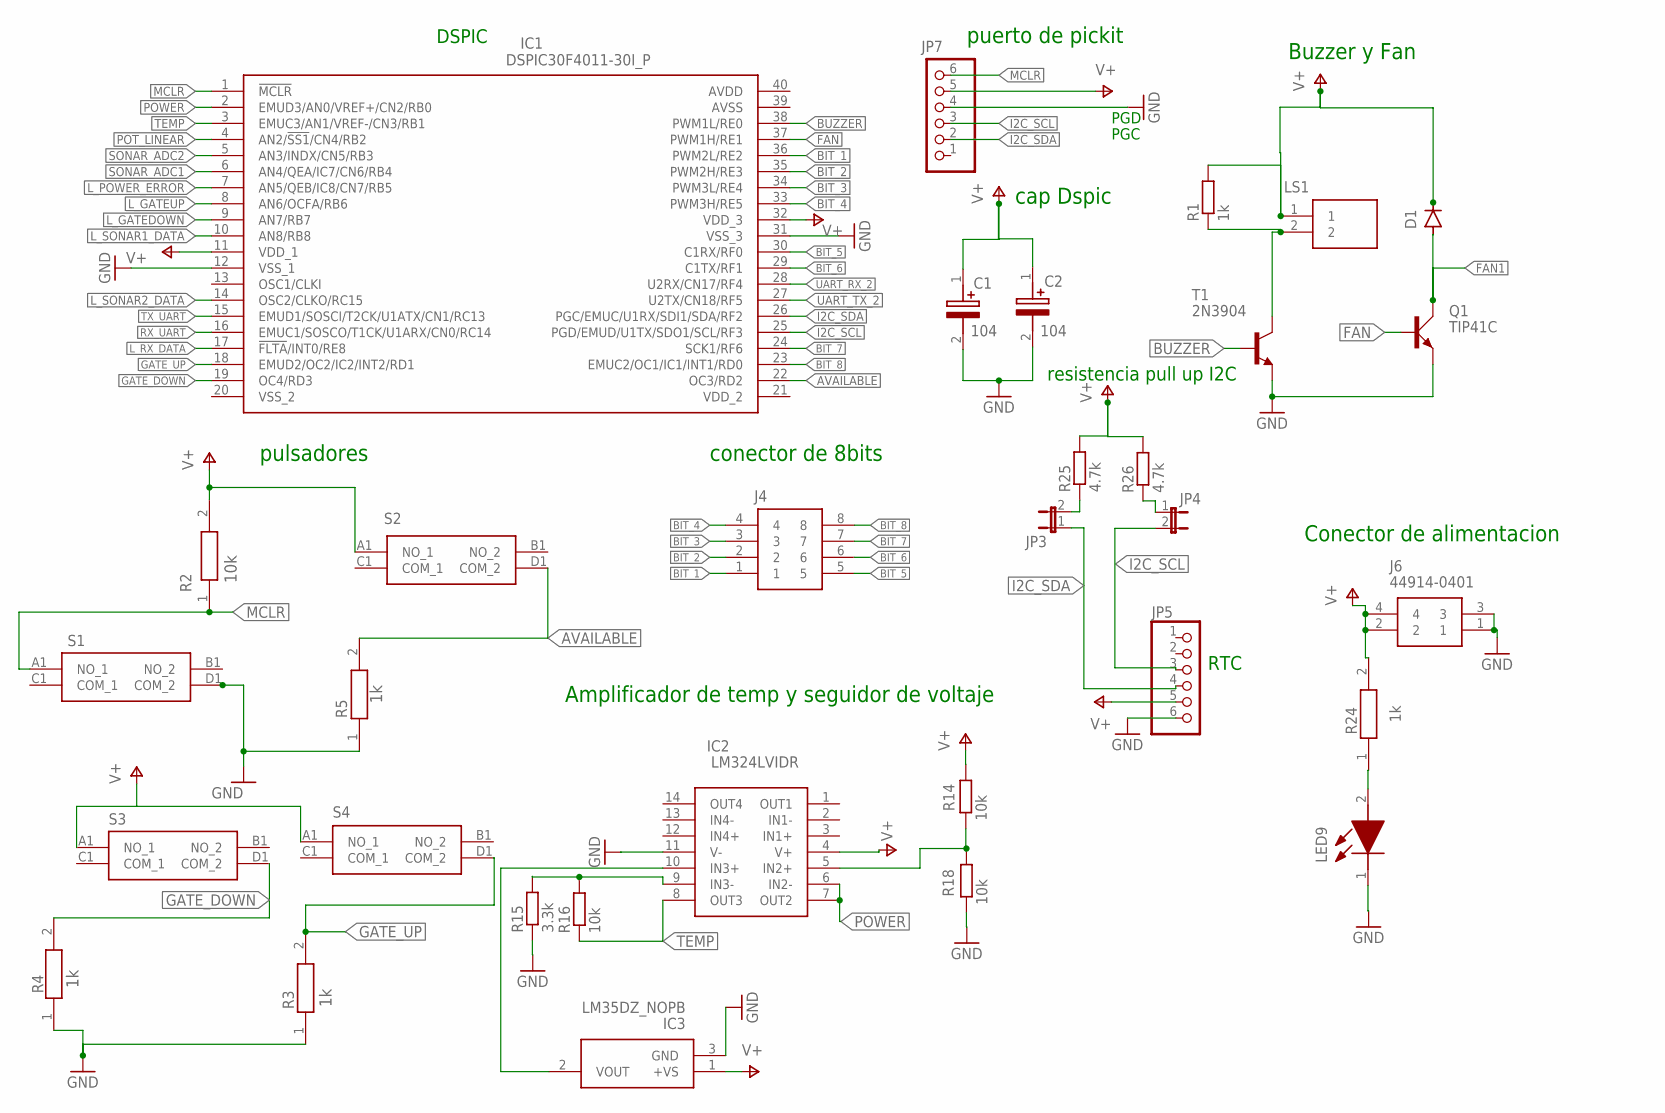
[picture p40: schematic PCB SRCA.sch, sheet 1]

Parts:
C1, C2: TAJR104K020RNJ; CAPPM2014X120N
D1: 1N4148DO35-7; DO35-7
IC1: DSPIC30F4011-30I_P; DIP1543W58P254L5175H635Q40N
IC2: LM324LVIDR; SOIC127P600X175-14N
IC3: LM35DZ_NOPB; LP0003A
J4: 44914-0801
J6: 44914-0401
JP3, JP4: JP1E; JP1
JP5, JP7: PINHD-1X6; 1X06
LED9: 599-0181-007F; LEDC2012X70N
LS1: PS1240P02BT
Q1: TIP41C; TO220AV
R1: 1k; 0207/10
R2, R3, R4, R5, R24: RC0805FR-071KL; RESC2012X60N
R14, R16, R18: 10k; 0207/10
R15: 3.3k; 0207/10
R25, R26: 4.7k; 0207/10
S1, S2, S3, S4: PTS645SK50JSMTR92_LFS; PTS645SK50JSMTR92LFS
T1: 2N3904; TO92

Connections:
AVAILABLE: IC1.22 (OC3/RD2), R5.2, S2.D1 (COM_2)
BIT_1: IC1.36 (PWM2L/RE2), J4.1
BIT_2: IC1.35 (PWM2H/RE3), J4.2
BIT_3: IC1.34 (PWM3L/RE4), J4.3
BIT_4: IC1.33 (PWM3H/RE5), J4.4
BIT_5: IC1.30 (C1RX/RF0), J4.5
BIT_6: IC1.29 (C1TX/RF1), J4.6
BIT_7: IC1.24 (SCK1/RF6), J4.7
BIT_8: IC1.23 (EMUC2/OC1/IC1/INT1/RD0), J4.8
BUZZER: IC1.38 (PWM1L/RE0), T1.2 (B)
FAN: IC1.37 (PWM1H/RE1), Q1.B
FAN1: D1.A, Q1.C; also elsewhere on the board
GATE_DOWN: IC1.19 (OC4/RD3), R4.2, S3.D1 (COM_2)
GATE_UP: IC1.18 (EMUD2/OC2/IC2/INT2/RD1), R3.2, S4.D1 (COM_2)
GND: C1.2 (-), C2.2 (-), IC1.12 (VSS_1), IC1.31 (VSS_3), IC2.11 (V-), IC3.3 (GND), J6.1, J6.3, JP5.6, JP7.4, LED9.1 (K), Q1.E, R3.1, R4.1, R5.1, R15.1, R18.1, S1.D1 (COM_2), T1.3 (E); also elsewhere on the board
I2C_SCL: IC1.25 (PGD/EMUD/U1TX/SDO1/SCL/RF3), JP4.2, JP5.3, JP7.3; also elsewhere on the board
I2C_SDA: IC1.26 (PGC/EMUC/U1RX/SDI1/SDA/RF2), JP3.1, JP5.4, JP7.2; also elsewhere on the board
L_GATEDOWN: IC1.9 (AN7/RB7); also elsewhere on the board
L_GATEUP: IC1.8 (AN6/OCFA/RB6); also elsewhere on the board
L_POWER_ERROR: IC1.7 (AN5/QEB/IC8/CN7/RB5); also elsewhere on the board
L_RX_DATA: IC1.17 (!FLTA!/INT0/RE8); also elsewhere on the board
L_SONAR1_DATA: IC1.10 (AN8/RB8); also elsewhere on the board
L_SONAR2_DATA: IC1.14 (OSC2/CLKO/RC15); also elsewhere on the board
MCLR: IC1.1 (!MCLR), JP7.6, R2.1, S1.A1 (NO_1)
unnamed: IC2.9 (IN3-), R15.2, R16.2
unnamed: IC2.10 (IN3+), IC3.2 (VOUT)
unnamed: JP3.2, R25.1
unnamed: LS1.2, R1.1, T1.1 (C)
unnamed: LED9.2 (A), R24.1
unnamed: JP4.1, R26.1
unnamed: IC2.5 (IN2+), R14.1, R18.2
POT_LINEAR: IC1.4 (AN2/!SS1!/CN4/RB2); also elsewhere on the board
POWER: IC1.2 (EMUD3/AN0/VREF+/CN2/RB0), IC2.6 (IN2-), IC2.7 (OUT2)
RX_UART: IC1.16 (EMUC1/SOSCO/T1CK/U1ARX/CN0/RC14); also elsewhere on the board
SONAR_ADC1: IC1.6 (AN4/QEA/IC7/CN6/RB4); also elsewhere on the board
SONAR_ADC2: IC1.5 (AN3/INDX/CN5/RB3); also elsewhere on the board
TEMP: IC1.3 (EMUC3/AN1/VREF-/CN3/RB1), IC2.8 (OUT3), R16.1
TX_UART: IC1.15 (EMUD1/SOSCI/T2CK/U1ATX/CN1/RC13); also elsewhere on the board
UART_RX_2: IC1.28 (U2RX/CN17/RF4); also elsewhere on the board
UART_TX_2: IC1.27 (U2TX/CN18/RF5); also elsewhere on the board
V+: C1.1 (+), C2.1 (+), D1.C, IC1.11 (VDD_1), IC1.32 (VDD_3), IC2.4 (V+), IC3.1 (+VS), J6.2, J6.4, JP5.5, JP7.5, LS1.1, R1.2, R2.2, R14.2, R24.2, R25.2, R26.2, S2.A1 (NO_1), S3.A1 (NO_1), S4.A1 (NO_1); also elsewhere on the board

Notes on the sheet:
pulsadores
Amplificador de temp y seguidor de voltaje
conector de 8bits
cap Dspic
puerto de pickit
Conector de alimentacion
resistencia pull up I2C
RTC
DSPIC
10k
104
Buzzer y Fan
PGD
PGC

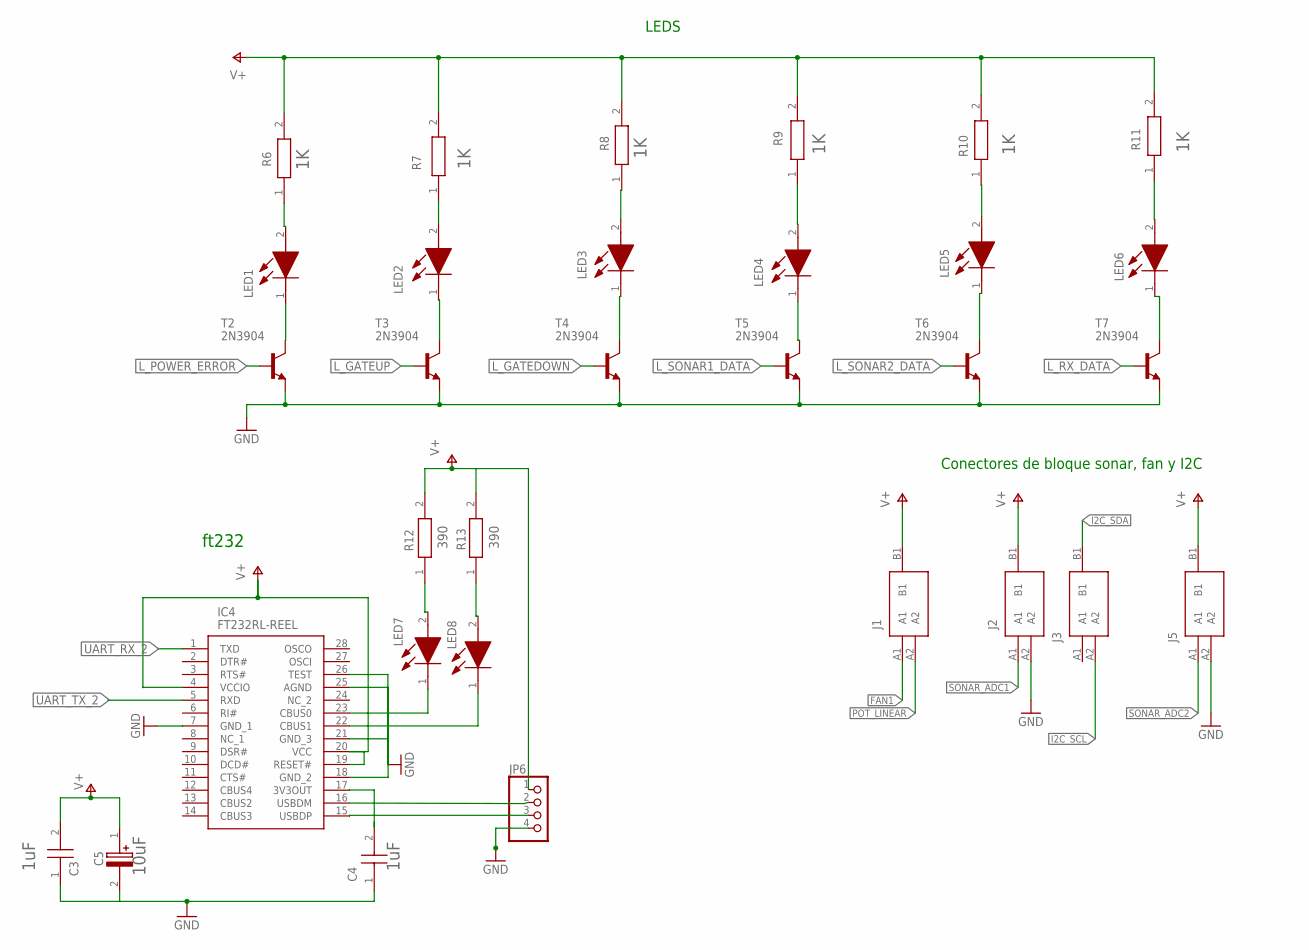
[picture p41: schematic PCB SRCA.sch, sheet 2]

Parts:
C3, C4: C0805X104K1RAC3316; CAPC2012X100N
C5: UUP1C100MCL1GS; CAPAE530X610N
IC4: FT232RL-REEL; SOP65P778X200-28N
J1, J2, J3, J5: TBL002A-350-03GR-2OR; TBL002A35003GR2OR
JP6: PINHD-1X4; 1X04
LED1, LED2, LED3, LED4, LED5, LED6, LED7, LED8: 599-0181-007F; LEDC2012X70N
R6, R7, R8, R9, R10, R11, R12, R13: RC0805FR-071KL; RESC2012X60N
T2, T3, T4, T5, T6, T7: 2N3904; TO92

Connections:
FAN1: J1.A1; also elsewhere on the board
GND: C3.1, C4.1, C5.2 (-), IC4.7 (GND_1), IC4.18 (GND_2), IC4.21 (GND_3), IC4.25 (AGND), IC4.26 (TEST), J2.A2, J5.A2, JP6.4, T2.3 (E), T3.3 (E), T4.3 (E), T5.3 (E), T6.3 (E), T7.3 (E); also elsewhere on the board
I2C_SCL: J3.A2; also elsewhere on the board
I2C_SDA: J3.B1; also elsewhere on the board
L_GATEDOWN: T4.2 (B); also elsewhere on the board
L_GATEUP: T3.2 (B); also elsewhere on the board
L_POWER_ERROR: T2.2 (B); also elsewhere on the board
L_RX_DATA: T7.2 (B); also elsewhere on the board
L_SONAR1_DATA: T5.2 (B); also elsewhere on the board
L_SONAR2_DATA: T6.2 (B); also elsewhere on the board
unnamed: LED1.2 (A), R6.1
unnamed: IC4.23 (CBUS0), LED7.1 (K)
unnamed: LED1.1 (K), T2.1 (C)
unnamed: LED2.2 (A), R7.1
unnamed: LED2.1 (K), T3.1 (C)
unnamed: LED3.1 (K), T4.1 (C)
unnamed: LED4.2 (A), R9.1
unnamed: LED5.2 (A), R10.1
unnamed: LED3.2 (A), R8.1
unnamed: LED4.1 (K), T5.1 (C)
unnamed: LED6.2 (A), R11.1
unnamed: LED7.2 (A), R12.1
unnamed: LED8.2 (A), R13.1
unnamed: LED5.1 (K), T6.1 (C)
unnamed: LED6.1 (K), T7.1 (C)
unnamed: IC4.22 (CBUS1), LED8.1 (K)
unnamed: C4.2, IC4.17 (3V3OUT)
unnamed: IC4.16 (USBDM), JP6.2
unnamed: IC4.15 (USBDP), JP6.3
POT_LINEAR: J1.A2; also elsewhere on the board
SONAR_ADC1: J2.A1; also elsewhere on the board
SONAR_ADC2: J5.A1; also elsewhere on the board
UART_RX_2: IC4.1 (TXD); also elsewhere on the board
UART_TX_2: IC4.5 (RXD); also elsewhere on the board
V+: C3.2, C5.1 (+), IC4.4 (VCCIO), IC4.19 (RESET#), IC4.20 (VCC), J1.B1, J2.B1, J5.B1, JP6.1, R6.2, R7.2, R8.2, R9.2, R10.2, R11.2, R12.2, R13.2; also elsewhere on the board

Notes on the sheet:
Conectores de bloque sonar, fan y I2C
LEDS
390
ft232
1uF
10uF

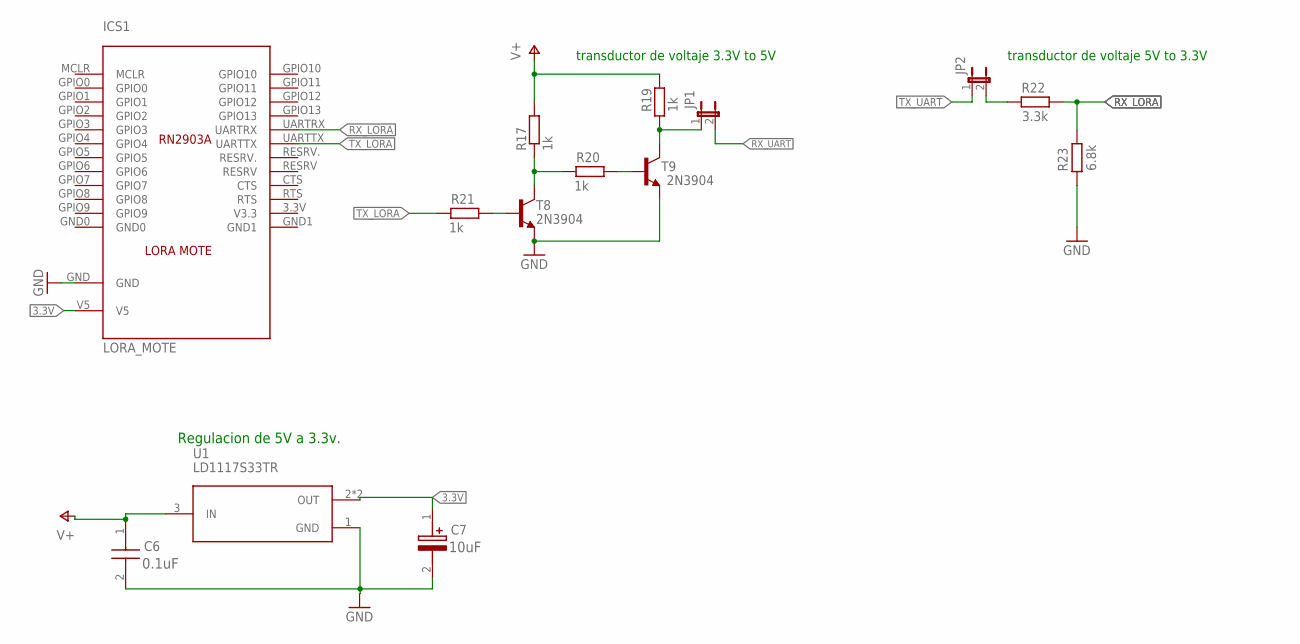
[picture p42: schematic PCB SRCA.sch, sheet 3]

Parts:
C6: C0805X104K1RAC3316; CAPC2012X100N
C7: UUP1C100MCL1GS; CAPAE530X610N
ICS1: LORA_MOTE; LORA_MOTE_RN2903
JP1, JP2: JP1E; JP1
R17, R19, R20, R21: 1k; 0207/10
R22: 3.3k; 0207/10
R23: 6.8k; 0207/10
T8, T9: 2N3904; TO92
U1: LD1117S33TR; SOT230P700X180-4N

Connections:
3.3V: C7.1 (+), ICS1.V5, U1.2 (OUT), U1.4 (OUT)
GND: C6.2, C7.2 (-), ICS1.GND, R23.2, T8.3 (E), T9.3 (E), U1.1 (GND); also elsewhere on the board
unnamed: R17.1, R20.2, T8.1 (C)
unnamed: R21.1, T8.2 (B)
unnamed: R20.1, T9.2 (B)
unnamed: JP2.2, R22.2
unnamed: JP1.1, R19.1, T9.1 (C)
RX_LORA: ICS1.UARTRX, R22.1, R23.1
RX_UART: JP1.2; also elsewhere on the board
TX_LORA: ICS1.UARTTX, R21.2
TX_UART: JP2.1; also elsewhere on the board
V+: C6.1, R17.2, R19.2, U1.3 (IN); also elsewhere on the board

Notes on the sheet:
transductor de voltaje 3.3V to 5V
transductor de voltaje 5V to 3.3V
Regulacion de 5V a 3.3v.
0.1uF
10uF

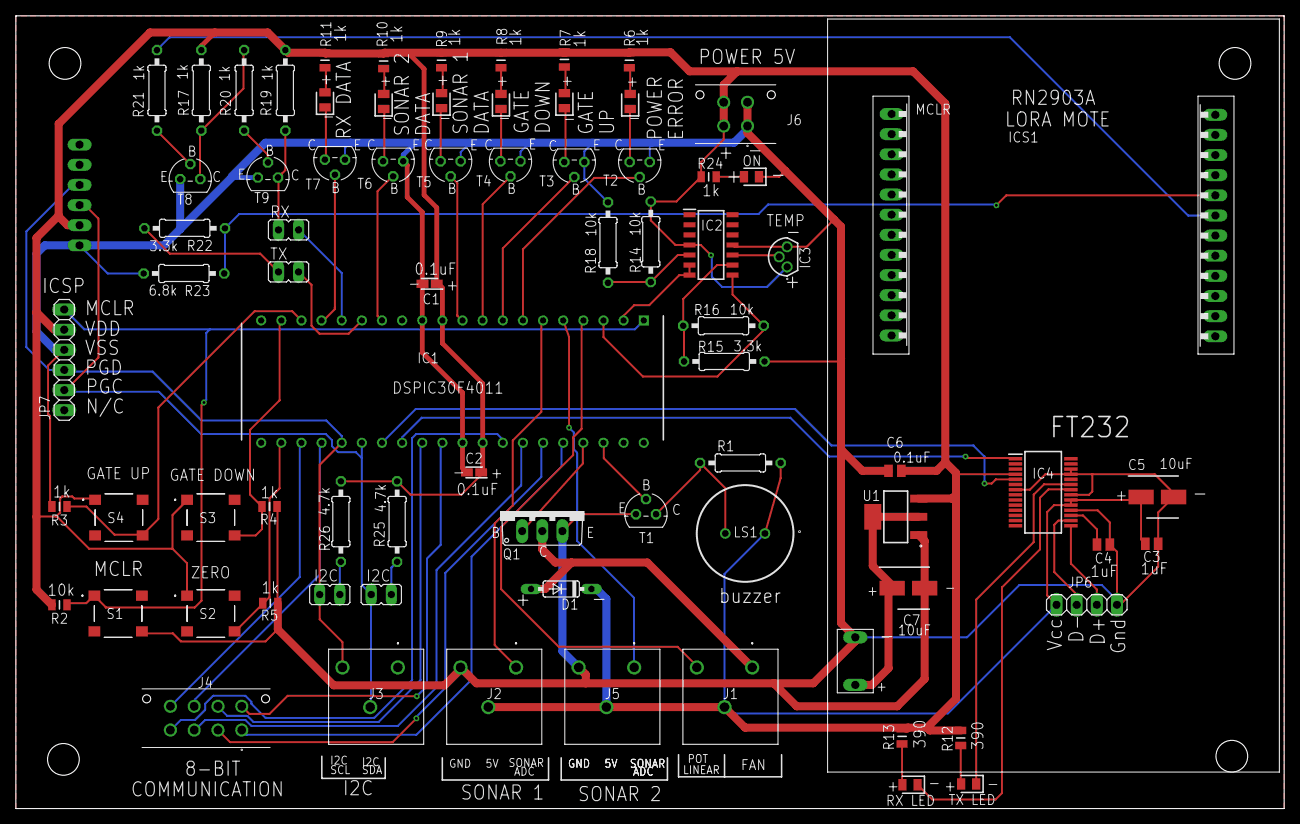
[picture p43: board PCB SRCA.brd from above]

Board: 2 copper layers, 160.0 x 100.0 mm, 77 parts (1 on the bottom side), 68 nets.

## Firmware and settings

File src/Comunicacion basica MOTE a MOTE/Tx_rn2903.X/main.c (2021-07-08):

#include "mcc_generated_files/mcc.h"
#include "SSD1306oLED.h"
#include "Hardware.h"
#include <stdio.h>
#include <stdbool.h>
#include <string.h>
#include <pic18lf45k50.h>

char cmd_message[16];

// INICIALICAON DE LOS PUERTO DEL MICROCONTROLADOR 
void init_port(void)
{   //TRANSMISOR
    LED_RED_TRIS = 0;
    LED_RED_LAT = 0;
    //RECEPTOR
    LED_GREEN_TRIS = 0;
    LED_GREEN_LAT = 0;
    // LCD
    TRISD = 0b00000000;
}
///// FUNCION DE LARGO TIEMPO
void delayms(uint16_t length)
{
    uint16_t counter;
    for(counter = 0; counter < length; counter++)
    {
        __delay_ms(1);
    }
}
// FUNCION QUE ENVIA DATOS CONCRETOS CR Y NF
void Endline(void)
{
    EUSART1_Write(0x0D); // CR; retorno de carro"enter" 
    EUSART1_Write(0x0A); // NF; salto del linea
}
// lo que hace esta fucion es tomar una cadena de texto y enviar cada elemento del texto
void sendCommand(char  * texto)
{ 
    while(* texto)
    {
        EUSART1_Write(* texto);
        texto++;
    }
   // Endline();
}

// FUNCION DE TESTEO DE LEDS CON PIC
void test_leds(void)
{    
    oled_putString("LED Test:",0,1);
//    moteApp_toggleLeds(true);
    LED_GREEN_LAT = 1;
    LED_RED_LAT = 1;
     delayms(500);
    LED_GREEN_LAT = 0;
    LED_RED_LAT = 0;
    delayms(500);
    LED_GREEN_LAT = 1;
    LED_RED_LAT = 1;
    delayms(500);
    LED_GREEN_LAT = 0;
    LED_RED_LAT = 0;
    delayms(500);
}

// FUNCION DE DE ENCENDIDO DE LEDS EN MODULO RN
void RN_Leds(bool state)
{
    __delay_ms(16);
    __delay_ms(16);
    __delay_ms(16);
    if (state)
    {
        sendCommand("sys set pindig GPIO10 1\r\n");
        __delay_ms(16);
        __delay_ms(16);
        __delay_ms(16);
        sendCommand("sys set pindig GPIO11 1\r\n");
    }
    else
    {
        sendCommand("sys set pindig GPIO10 0\r\n");
        __delay_ms(16);
        __delay_ms(16);
        __delay_ms(16);
        sendCommand("sys set pindig GPIO11 0\r\n");
    }
}
// esta funcion inicaliza los parametreos de la seccion de radio para la comunicacoin


//// HAROLD//

void read_LoRA_cmd(void){
    int i=0,Flag=0;                 
    
    ///// Clear message buffer
    for (i = 0; i <= 15; i++){
        cmd_message[i]=0;
    }
    /////
    
    i=0;
    while(Flag==0)      
    {
        cmd_message[i] = get_Data();
        if((cmd_message[i]) == '\r'){
            cmd_message[i] = ' ';
            get_Data(); // for \n
            Flag=1;
        }  
        if (i>16){
            while(get_Data() !='\n'){} // \n
            break;
        }
        i++;
    }
}

void Opening(){
    uint8_t size=16;
    char aux[16] = "   UNIBAGUE    ";
    uint8_t i = 0;
    
    oled_clear();
    oled_putString(" LoRA MOTE SI2C ",0,0);  // colum 0, row 0
    for (i = 0; i < size-1; i++){
        oled_putChar((aux[i]),i,1);
        __delay_ms(100);
    }
    LED_RED_LAT = 1;
    LED_GREEN_LAT = 1;
    oled_putString(">>Welcome!",0,3);
    __delay_ms(1000);
    LED_RED_LAT = 0;
    LED_GREEN_LAT = 0;
}

void init_mod_LoRa(void)
{   
    Opening();
    oled_clear();
    ////// SYS VERSION
    oled_putString("SYS Version:",0,1);
    oled_putString(">>",0,2);
    sendCommand("sys get ver\r\n");
    read_LoRA_cmd();
    oled_putString(cmd_message,0,3);       // colum 0, row 3
    __delay_ms(1000);

    //////
    
    ////// POWER    
    oled_clear();
    oled_putString("Config module RN",0,0);
    oled_putString(" POWER: 3 of 14",0,2);
    sendCommand("radio set pwr 3\r\n");  // output Power
    read_LoRA_cmd();
    oled_putString(&cmd_message,0,3);       // colum 0, row 3
    __delay_ms(1000);
    //////
    
    ////// BW
    oled_clear();
    oled_putString("Band BW",0,1);
    oled_putString(" WIDEBAND: 250",0,2);
    sendCommand("radio set bw 250\r\n");   //fAncho de banda del radio"  
    read_LoRA_cmd();
    oled_putString(&cmd_message,0,3);       // colum 0, row 3
    __delay_ms(1000);
    //////
    
    ////// FREQ
    oled_clear();
    oled_putString("Frequency FQ",0,1);
    oled_putString(" FREQ: 9.233 MHZ",0,2);
    sendCommand("radio set freq 923300000\r\n");   //frecuencia de operacion de la radio  
    read_LoRA_cmd();
    oled_putString(&cmd_message,0,3);       // colum 0, row 3
    __delay_ms(1000);
    //////
    
    ////// CODE ERROR
    oled_clear();
    oled_putString("CODE ERROR",0,1);
    oled_putString(" Enables the CRC",0,2);
    sendCommand("radio set crc on\r\n");     
    read_LoRA_cmd();
    oled_putString(&cmd_message,0,3);       // colum 0, row 3
    __delay_ms(1000);
    //////
    
    
    ////// LoRA MODE
    oled_clear();
    oled_putString("LoRA MODE",0,1);
    oled_putString(" LoRA modulation",0,2);
    sendCommand("radio set mod lora\r\n");   
    read_LoRA_cmd();
    oled_putString(&cmd_message,0,3);       // colum 0, row 3
    __delay_ms(1000);
    //////
    
    
    ////// LoRA Inversion
    oled_clear();
    oled_putString("LoRA Inversion",0,1);
    oled_putString(" Invert IQ off",0,2);
    sendCommand("radio set iqi off\r\n");     
    read_LoRA_cmd();
    oled_putString(&cmd_message,0,3);       // colum 0, row 3
    __delay_ms(1000);
    //////
    
    
    ////// LoRA WDT
    oled_clear();
    oled_putString("LoRA WDT",0,1);
    oled_putString(" WDT each 1sec",0,2);
    sendCommand("radio set wdt 1000\r\n");     
    read_LoRA_cmd();
    oled_putString(&cmd_message,0,3);       // colum 0, row 3
    __delay_ms(1000);
    //////
    
    ////// Dispersion Factor
    oled_clear();
    oled_putString("SPR. Factor",0,1);
    oled_putString(" spreadingFact12",0,2);
    sendCommand("radio set sf SF12\r\n");     
    read_LoRA_cmd();
    oled_putString(&cmd_message,0,3);       // colum 0, row 3
    __delay_ms(1000);
    //////
    
    ////// LoRA Sync
    oled_clear();
    oled_putString("LoRA Sync",0,1);
    oled_putString(" Sync word 34",0,2);
    sendCommand("radio set sync 34\r\n");   
    read_LoRA_cmd();
    oled_putString(&cmd_message,0,3);       // colum 0, row 3
    __delay_ms(1000);
    //////        
    
}


void main(void)
{
    SYSTEM_Initialize();
    init_port();
    delayms(500);
    // Prepare LCD Backlight
    oled_init();         // Display   
    init_mod_LoRa();
    oled_clear();
    char read[32];//guarda el numero ASCII
    uint8_t cont = 0;
    while (1)
    {   
        if(cont <1)
        {
            oled_putString("MAC PAUSE",0,0);
            sendCommand("mac pause\r\n");        // "pausa la funcionalidad de la pila para configura el transeptor " 
            read_LoRA_cmd();
            oled_putString(&cmd_message,0,1);
         }
        else if(cont == 1)
        {
            oled_clear();
            oled_putString("transmision=H",0,0);
            sendCommand("radio tx 48656c6C6F\r\n");   //"Transmision simple de paquetes" 
            read_LoRA_cmd();
            oled_putString(&cmd_message,0,1);
        }
        else if(cont == 2)
        {
            oled_clear();
            oled_putString("transmision=20",0,0);
            sendCommand("radio tx 20\r\n");   //"Transmision simple de paquetes" 
            read_LoRA_cmd();
            oled_putString(&cmd_message,0,1);
        }
        else if(cont == 3)
        {
            oled_clear();
            oled_putString("transmision=30",0,0);
            sendCommand("radio tx 30\r\n");   //"Transmision simple de paquetes" 
            read_LoRA_cmd();
            oled_putString(&cmd_message,0,1);
        }
        else if(cont == 4)
        {
            oled_clear();
            oled_putString("transmision=40",0,0);
            sendCommand("radio tx 40\r\n");   //"Transmision simple de paquetes" 
            read_LoRA_cmd();
            oled_putString(&cmd_message,0,1);
        }
        else if(cont == 5)
        {
            oled_clear();
            oled_putString("transmision=50",0,0);
            sendCommand("radio tx 50\r\n");   //"Transmision simple de paquetes" 
            read_LoRA_cmd();
            oled_putString(&cmd_message,0,1);
        }
        else if(cont == 6)
        {
            oled_clear();
            oled_putString("transmision=60",0,0);
            sendCommand("radio tx 60\r\n");   //"Transmision simple de paquetes" 
            read_LoRA_cmd();
            oled_putString(&cmd_message,0,1);
        }
         else if(cont == 7)
        {
            oled_clear();
            oled_putString("transmision=70",0,0);
            sendCommand("radio tx 70\r\n");   //"Transmision simple de paquetes" 
            read_LoRA_cmd();
            oled_putString(&cmd_message,0,1);
        }
        else if(cont == 8)
        {
            oled_clear();
            oled_putString("transmision=80",0,0);
            sendCommand("radio tx 80\r\n");   //"Transmision simple de paquetes" 
            read_LoRA_cmd();
            oled_putString(&cmd_message,0,1);
        }
        else if(cont == 9)
        {
            oled_clear();
            oled_putString("transmision=90",0,0);
            sendCommand("radio tx 90\r\n");   //"Transmision simple de paquetes" 
            read_LoRA_cmd();
            oled_putString(&cmd_message,0,1);
        }
        else if(cont == 10)
        {
            oled_clear();
            oled_putString("Mac resume",0,0);
            sendCommand("mac resume\r\n");    //"reanuda la funcionalidad de la pila despues de estar en pausa "
            read_LoRA_cmd();
            oled_putString(&cmd_message,0,1);
            delayms(2000);
            oled_clear();
            oled_putString("MAC Pause",0,0);
            sendCommand("mac pause\r\n");        // "pausa la funcionalidad de la pila para configura el transeptor " 
            read_LoRA_cmd();
            oled_putString(&cmd_message,0,1);
        }
        else if(cont > 10){
            cont=0;
        }
        cont++; /// inceremento  del contaldor 
        delayms(1000);
    }
}

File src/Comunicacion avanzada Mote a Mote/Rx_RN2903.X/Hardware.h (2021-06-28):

#include <xc.h>
#ifndef HARDWARE__H
#define HARDWARE__H


/*******************************************************************/
/******** PORT/LAT/TRIS *************************/
/*******************************************************************/
/******** -A- *************************/
#define LATA_INIT       0b00000000  // LAT Init value
#define TRISA_INIT      0b11111111  // TRIS Init value  (0=Output)
#define ANSELA_INIT     0b00000000  // ANSEL Init value (1=Analog)
#define ODCA_INIT       0b00000000  // ODC Init value   (1=Open Drain)



/******** -2- *************************/
#define TEMP_SENSOR_PORT    PORTAbits.RA2
#define TEMP_SENSOR_LAT     LATAbits.LATA2
#define TEMP_SENSOR_TRIS    TRISAbits.TRISA2
#define TEMP_SENSE_ANSEL    ANSELAbits.ANSA2
/******** -3- *************************/
#define LIGHT_SENSOR_PORT   PORTAbits.RA3
#define LIGHT_SENSOR_LAT    LATAbits.LATA3
#define LIGHT_SENSOR_TRIS   TRISAbits.TRISA3
#define LIGHT_SENSE_ANSEL   ANSELAbits.ANSA3

/******** -5- *************************/
#define SENSE_PWR_PORT    PORTAbits.RA5
#define SENSE_PWR_LAT     LATAbits.LATA5
#define SENSE_PWR_TRIS    TRISAbits.TRISA5
/******** -6- *************************/
#define LED_GREEN_PORT    PORTAbits.RA6
#define LED_GREEN_LAT     LATAbits.LATA6
#define LED_GREEN_TRIS    TRISAbits.TRISA6
/******** -7- *************************/
#define LED_RED_PORT    PORTAbits.RA7
#define LED_RED_LAT     LATAbits.LATA7
#define LED_RED_TRIS    TRISAbits.TRISA7

/******** -B- *************************/
#define LATB_INIT       0b00000000  // LAT Init value
#define TRISB_INIT      0b11111111  // TRIS Init value  (0=Output)
#define ANSELB_INIT     0b00000000  // ANSEL Init value (1=Analog)
#define ODCB_INIT       0b00000000  // ODC Init value   (1=Open Drain)
/******** -0- *************************/
#define SWITCH_2_PORT    PORTBbits.RB0
#define SWITCH_2_LAT     LATBbits.LATB0
#define SWITCH_2_TRIS    TRISBbits.TRISB0
#define SWITCH_2_IOC     INTCONbits.INT0IE
/******** -1- *************************/
#define SWITCH_1_PORT    PORTBbits.RB1
#define SWITCH_1_LAT     LATBbits.LATB1
#define SWITCH_1_TRIS    TRISBbits.TRISB1
#define SWITCH_1_IOC     INTCON3bits.INT1IE
/******** -2- *************************/
#define LCD_RESET_PORT    PORTBbits.RB2
#define LCD_RESET_LAT     LATBbits.LATB2
#define LCD_RESET_TRIS    TRISBbits.TRISB2
/******** -3- *************************/
#define LCD_RDN_EN_PORT    PORTBbits.RB3
#define LCD_RDN_EN_LAT     LATBbits.LATB3
#define LCD_RDN_EN_TRIS    TRISBbits.TRISB3
/******** -4- *************************/
#define LCD_CS_PORT    PORTBbits.RB4
#define LCD_CS_LAT     LATBbits.LATB4
#define LCD_CS_TRIS    TRISBbits.TRISB4
/******** -5- *************************/
#define MOD_RESET_PORT    PORTBbits.RB5
#define MOD_RESET_LAT     LATBbits.LATB5
#define MOD_RESET_TRIS    TRISBbits.TRISB5
/******** -6- *************************/
// Not Used
/******** -7- *************************/
// Not Used

/******** -C- *************************/
#define LATC_INIT       0b00000000  // LAT Init value
#define TRISC_INIT      0b11111111  // TRIS Init value  (0=Output)
#define ANSELC_INIT     0b00000000  // ANSEL Init value (1=Analog)
#define ODCC_INIT       0b00000000  // ODC Init value   (1=Open Drain)
/******** -0- *************************/
#define LCD_A0_PORT    PORTCbits.RC0
#define LCD_A0_LAT     LATCbits.LATC0
#define LCD_A0_TRIS    TRISCbits.TRISC0
/******** -1- *************************/
#define LCD_RW_PORT    PORTCbits.RC1
#define LCD_RW_LAT     LATCbits.LATC1
#define LCD_RW_TRIS    TRISCbits.TRISC1
/******** -2- *************************/
#define MODULE_WAKE_PORT    PORTCbits.RC2
#define MODULE_WAKE_LAT     LATCbits.LATC2
#define MODULE_WAKE_TRIS    TRISCbits.TRISC2
#define MODULE_WAKE_IOC     IOCCbits.IOCC2
/******** -6- *************************/
#define EUSART_TX_PORT    PORTCbits.RC6
#define EUSART_TX_LAT     LATCbits.LATC6
#define EUSART_TX_TRIS    TRISCbits.TRISC6
#define EUSART_TX_ANSEL   ANSELCbits.ANSC6
/******** -7- *************************/
#define EUSART_RX_PORT    PORTCbits.RC7
#define EUSART_RX_LAT     LATCbits.LATC7
#define EUSART_RX_TRIS    TRISCbits.TRISC7
#define EUSART_RX_ANSEL   ANSELCbits.ANSC7
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

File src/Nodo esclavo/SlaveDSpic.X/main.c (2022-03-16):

/*
 * File:   main.c
 * Author: Oscar Daniel Rodrguez Gallego 
 * Created on July 12, 2021, 10:23 PM
 * estructure on 1 de marzo de 2022, 01:55 PM
 */


#include "xc.h"
#include "Device_config.h"
#include <libpic30.h>
#include "UART.h"
#include "LoRa_RN2903A.h"
#include "ADC_Sensor_Driver.h"
#include "Led_Driver.h"
#include "Timers.h"
#include "serial_protocolo.h"
#include "I2C.h"
#include "DS3231.h"
#include "Buzzer_Driver.h"
#include "Button_Driver.h"
#include "Eightbits_protocol.h"

// funciones 
void Init_system(void);
void Read_String(void);
uint8_t Decode_LoRa_Read(void);
// varialbes de lectura de los adc y rtc
uint16_t sonar_H = 0; //1
uint16_t sonar_L = 0; //2
uint8_t temp = 0; //3
uint8_t power = 0; //4
uint8_t Current_Gate_Value = 0; //5
uint32_t Time = 0; //6
uint32_t Date = 0; //7
////Variables para guardar los datos 
char Data;
char buffer_RX[40];
char LoRA_data[40];
int cont_aux = 0;
uint32_t sampling_time_send_aux = 100, sampling_time_send = 2000;
uint32_t sampling_time_colletion_aux = 50, sampling_time_collection = 2000;
// varialbles de configuracion de RTC 
char TimeConfig[] = "122000";
char DateConfig[] = "090322";
//-----------------------------------------------------------funciones---------------------------------------------------------------------

void __attribute__((interrupt, auto_psv)) _T3Interrupt(void) {
    UART1_Send_Command("radio rxstop\r\n"); // se pausa la rececion continua para enviar el dato
    Read_String();
    //    Read_Time();
    //    Read_Date();
    //se apaga los ledes de los sonares 
    Led_Sonar1(0);
    Led_Sonar2(0);
    Led_Rx(1);

    Sensor_Reading_ADC();
    sonar_H = (uint16_t) Get_Volts_Sonar_1_ADC(); //1
    sonar_L = (uint16_t) Get_Volts_Sonar_2_ADC(); //2
    temp = (uint8_t) Get_Volts_Temp_ADC(); //3
    power = (uint8_t) (Get_Volts_Power_ADC()*20); //4 el dbole por 10veces 
    Current_Gate_Value = (uint8_t) Get_Percentage_Gate_ADC(); //5
    //aqui va la funcion para hacer el envio de los datos
    Send_Data_Pakect(254, 255, 1, sonar_H);
    Read_String();
    __delay_ms(600);
    //    Serial_putUint32(sonar_H);
    Send_Data_Pakect(254, 255, 2, sonar_L);
    Read_String();
    __delay_ms(600);
    //    Serial_putUint32(temp);
    Send_Data_Pakect(254, 255, 3, temp);
    Read_String();
    __delay_ms(600);
    Send_Data_Pakect(254, 255, 4, power);
    Read_String();
    __delay_ms(600);
    Serial_putUint32(Current_Gate_Value);
    Send_Data_Pakect(254, 255, 5, Current_Gate_Value);
    Read_String();
    __delay_ms(600);
    //        Serial_putUint32(Concatenate_Time());
    Send_Data_Pakect(254, 255, 6, Concatenate_Time());
    Read_String();
    __delay_ms(600);
    //    Serial_putUint32(Concatenate_Date());
    Send_Data_Pakect(254, 255, 7, Concatenate_Date());
    Read_String();
    Led_Rx(0);
    __delay_ms(600);
    UART1_Send_Command("radio rx 0\r\n");
    Read_String();

    // el tempo que demora es el que se configuro por parametro en milisegundo - 360s
    IFS0bits.T3IF = 0; // SE REINICIA LA BNADERA
    //  IFS1bits.T5IF = 0; // se pone en 0 par que no suceda la interrupcion de muestreo de datos 
}

void Read_String(void) {
    int i = 0;
    while (i < 40) {
        Data = UART1_Read();
        buffer_RX[i] = Data;
        if (Data == '\n') {
            UART2_Send_Command("datos:");
            UART2_Send_Command(buffer_RX);
            break;
        }
        i++;
    }
}

uint8_t Decode_LoRa_Read(void) {
    /*
     * Elimina las partes de inicio y final del mensaje 
     */
    // This function saves in LoRA_RX_data the received data
    uint8_t dataType = 0, flag = 0, i = 0;
    /*
     dataType 1 = "Ok"
     dataType 2 = "radio_err"
     dataType 3 = "invalid_param"
     dataType 4 = "busy"
     dataType 5 = "radio_rx" <data> 
     */
    // Type of RX info
    UART2_Write(buffer_RX[0]);
    UART2_Write(buffer_RX[1]);
    UART2_Write(buffer_RX[2]);
    UART2_Write(buffer_RX[3]);
    UART2_Write(0x20);
    if (buffer_RX[0] == 'o' && buffer_RX[1] == 'k') {
        dataType = 1;
    } else if (buffer_RX[5] == '_' && buffer_RX[6] == 'e' && buffer_RX[7] == 'r') {
        dataType = 2;
    } else if (buffer_RX[0] == 'i' && buffer_RX[1] == 'n' && buffer_RX[2] == 'v') {
        dataType = 3;
    } else if (buffer_RX[0] == 'b' && buffer_RX[1] == 'u' && buffer_RX[2] == 's') {
        dataType = 4;
    } else if (buffer_RX[5] == '_' && buffer_RX[6] == 'r' && buffer_RX[7] == 'x') {
        dataType = 5;
    } else {
        dataType = 0;
    }

    Serial_putUint32(dataType);
    /// Remove "radio_rx " from LoRA Answer "radio_rx data$..."
    if (dataType == 5) {
        //for (i = 0; i < buff_size; i++)
        while (buffer_RX[i] != '\0') { //+9
            if (buffer_RX[i + 11] != '\r' && flag == 0) {
                LoRA_data[i] = buffer_RX[i + 11];
            } else {
                flag = 1;
                break;
            }
            i++;
        }
    }
    //--------------------------------- se limpiar le buffer que alamacena las lecturas uart
    i = 0;
    while (buffer_RX[i] != '\0') {
        buffer_RX[i] = 0;
        i++;
    }
    return dataType;
}

void Init_system(void) {
    Init_UART1();
    Init_UART2();
    Init_mod_LoRa();
    UART2_Send_Command("recepcion on \n");
    UART1_Send_Command("mac pause\r\n");
    Read_String();
    __delay_ms(400);
    UART1_Send_Command("radio rx 0\r\n");
    Read_String();
    __delay_ms(400);
    Init_ADC_Sensors_Driver();
    Init_Percentage(4.5, 1.5);
    Init_Led_Driver();
    Turn_on_pic();
    Init_I2C();
    Init_Buzzer_Driver();
    Init_Button_Driver();
    Init_SamplingTimeSend(60000); //60segundos
    Init_Eightbist_protocol();
    Opening_Buz();
}

int main(void) {
    Init_system();
    while (1) {
        //se lee el uart si hay datos
        if (U1STAbits.URXDA == 1) {
            Led_Rx(1);
            Read_String();
            uint8_t dataType = Decode_LoRa_Read();
            if (dataType == 5) {
                UART2_Send_Command("New data:");
                UART2_Send_Command(LoRA_data);
                UART2_Write('\n');
                Decode_Data_Pakect(LoRA_data);
            }
            __delay_ms(10);
            UART1_Send_Command("radio rx 0\r\n");
            Read_String();
            Led_Rx(0);
        }
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

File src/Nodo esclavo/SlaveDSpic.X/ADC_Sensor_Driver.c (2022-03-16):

/*
 * File:   Channel_Gate.c
 * Position : Estudiante de Paz y Region 
 * Author: Johan Avila 
 * Mail  : ingenieroavila21@gmail.com
 * Reviewer and approver  : Oscar Daniel Rodriguez Gallego
 * Change : Oscar Daniel Rodrguez Gallego
 */

#include <xc.h>

#include "ADC_Sensor_Driver.h"
#include "LoRa_RN2903A.h"

const float Resolution_ADC = (5.0) / (1024); // (AVDD / 2^10bit) 
// ok
float Volts_Power_ADC = 0.0; // RB0
float Volts_Temp_ADC = 0.0; // RB1
float Volts_Gate_ADC = 0.0; // RB2
float Volts_Sonar_2_ADC = 0.0; // RB3
float Volts_Sonar_1_ADC = 0.0; // RB4
float Voltaje_max=0.0,Voltaje_min=0.0;

void Init_ADC_Sensors_Driver(void) {
    // ADPCFG configuration ok
    TRISBbits.TRISB0 = 1;
    TRISBbits.TRISB1 = 1;
    TRISBbits.TRISB2 = 1;
    TRISBbits.TRISB3 = 1;
    TRISBbits.TRISB4 = 1;
    // digital ports 1 ; analog ports 0; ports B
    ADPCFGbits.PCFG0 = 0; // RB0 intput analog ports
    ADPCFGbits.PCFG1 = 0; // RB1 intput analog ports
    ADPCFGbits.PCFG2 = 0; // RB2 intput analog ports  
    ADPCFGbits.PCFG3 = 0; // RB3 intput analog ports
    ADPCFGbits.PCFG4 = 0; // RB4 intput analog ports
        // ADCON1 configuration ok
    ADCON1bits.ADSIDL = 0; // Continue module operation in Idle mode
    ADCON1bits.FORM = 0b00; // Data Output Format bits Integer
    ADCON1bits.SSRC = 0b000; // Clearing SAMP bit ends sampling and starts conversion
    ADCON1bits.SIMSAM = 0; // Samples multiple channels individually in sequence
    ADCON1bits.ASAM = 0; // A/D Sample Auto-Start bit,Sampling begins when SAMP bit set 

    // ADCON2 configuration ok
    ADCON2bits.VCFG = 0b000; // Voltage Reference(AVDD - AVSS)
    ADCON2bits.CSCNA = 0; // Do not scan inputs
    ADCON2bits.CHPS = 0b11; // Selects Channels Utilized CH0, CH1, CH2 and CH3
    ADCON2bits.BUFS = 1; //  A/D is currently filling buffer 0x8-0xF, user should access data in 0x0-0x7
    ADCON2bits.SMPI = 0b1000; // Sample/Convert Sequences Per Interrupt Selection bits
    ADCON2bits.BUFM = 1; // Buffer configured as two 8-word buffers ADCBUF(15...8), ADCBUF(7...0)
    ADCON2bits.ALTS = 1; // Uses MUX A input multiplexer settings for first sample, then alternate between MUX B and MUX A input multiplexer settings for all subsequent samples

    // ADCHS configuration ok
    // MUX A Multiplexer Setting bits
    ADCHSbits.CH123NA = 0b00; // CH1, CH2, CH3 negative input is VREF -
    ADCHSbits.CH123SA = 0; // CH1:AN0, CH2:AN1, CH3:AN2
    ADCHSbits.CH0NA = 0; // Channel 0 negative input is VREF-
    ADCHSbits.CH0SA = 0b0011; // CH0:AN3

    // MUX B Multiplexer Setting bits
    ADCHSbits.CH123NB = 0b00; // CH1, CH2, CH3 negative input is VREF -
    ADCHSbits.CH123SB = 0; // CH1:AN0, CH2:AN1, CH3:AN2
    ADCHSbits.CH0NB = 0; // Channel 0 negative input is VREF-
    ADCHSbits.CH0SB = 0b0100; // CH0:AN4

    // ADCSSL configuration add daniel rodriguez gallego
    ADCSSLbits.CSSL0 = 0;
    ADCSSLbits.CSSL1 = 0;
    ADCSSLbits.CSSL2 = 0;
    ADCSSLbits.CSSL3 = 0;
    ADCSSLbits.CSSL4 = 0;

    // ADCON3 configuration ok
    ADCON3bits.SAMC = 18; // Sample Time bits
    ADCON3bits.ADRC = 1; // A/D internal RC clock
    // TAD = 333.33 nsec
    // FCY = FOSC/4 120Mhz : 30Mhz
    // ADCS = ( (2*TAD) / (1/FCY) ) - 1
    ADCON3bits.ADCS = 9; // Conversion Clock Select bits
    
    ADCON1bits.ADON = 1; //  Conversion Status bit on
}

void Sensor_Reading_ADC(void) {

    ADCON1bits.SAMP = 1; // Bit para habilitar muestreo
    __delay_ms(10);
    ADCON1bits.SAMP = 0; // Retiene el muestreo

    // MUX A Multiplexer
    Volts_Power_ADC = (ADCBUF1 * Resolution_ADC ); // RB0
    Volts_Temp_ADC = (ADCBUF2 * Resolution_ADC * 100) / 4; // RB1 4 corresponde a la ganancia de AOP
    Volts_Gate_ADC = (ADCBUF3 * Resolution_ADC); // RB2  
    Volts_Sonar_2_ADC = (ADCBUF0 * 5); // RB3

    // MUX B Multiplexer
    Volts_Sonar_1_ADC = (ADCBUF4 * 5); // RB4
}

float Get_Volts_Power_ADC(void) {
    return Volts_Power_ADC;
}

float Get_Volts_Temp_ADC(void) {

    return Volts_Temp_ADC;
}

float Get_Percentage_Gate_ADC(void) {
    /*
     * como se tiene una condicion de un voltaje minimo y un voltaje maximo 
     * el porcentajes es una regla de 3, en la que la lectura del adc se le resta el voltaje minimo ya que este 
     * es un offeset, al igual se hace Voltaje maximo, la idea es que el voltaje minimo represente al cero
     * y el maximo al 100%
     */
    float percentage = ((Volts_Gate_ADC-Voltaje_min)*100)/(Voltaje_max - Voltaje_min);
    if(percentage<=0){
        percentage = 0;
    }else if(percentage >= 100)
    {
        percentage =100;
    }else{
        percentage = percentage;//el valor que tiene
    }
    return percentage;
}

float Get_Volts_Sonar_1_ADC(void) {
//    Led_Sonar1(1);
//    __delay_ms(50);
//    Led_Sonar1(0);
    return Volts_Sonar_1_ADC;
}

float Get_Volts_Sonar_2_ADC(void) {
//    Led_Sonar2(1);
//    __delay_ms(50);
//    Led_Sonar2(0);
    return Volts_Sonar_2_ADC;
}

void Init_Percentage(float Vmax, float Vmin){
    Voltaje_max = Vmax;
    Voltaje_min = Vmin; 
}

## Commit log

2021-04-01 datashet
    se agregaron los datasheet de el sensor ultra sonido, la tarjeta LoRa el Dspic.
2021-04-01 Diseño de PCB
2021-04-10 Correccion readme
    se agregaron los links de google drive, los link de la pagina oficial en la cual se compraron los componentes aun falta por especificar
    mas cosas
2021-04-14 schematic
    este documento contiene el desarrollos esquemático del pcb
2021-04-14 Update Readme.md
    Se arreglo el diagrama de bloques
2021-04-14 eagle
    esquematico con los pootprint
    [Tarjeta.sch]
2021-05-16 pdf tarjeta
    este pdf contiene el esquematico de las conexiones realizadas hasta el momento
2021-05-16 Esquematico
    se actulizo el esquematico
    [Tarjeta.sch]
2021-05-16 16/05/2021
    actualizacion
    [Tarjeta.sch]
2021-06-28 28/06/2021
    se agrego la documentación del código fuente de la tarjeta LoRa Mote
2021-06-29 29/06/2021
    actualización del firmware de una tarjeta loRa
2021-07-07 6/07/2021
    actualizacion de codigos de transmision y recepcion
2021-07-07 06/07/2021
    cambio de carpeta
2021-07-07 06/07/2021
    explicación de lorasuit y comandos
2021-07-07 07/07/2021
    Se agrego el proceso de instalación de los programas usados aun falta agregar la instalacion de lora suit
2021-07-08 07/07/2021
    Se termino de agregar los coma nos de radio
2021-07-15 14/07/2021
    actualizacIón de la PCB
    [PCB SRCA.brd, PCB SRCA.sch]
2021-07-21 21/07/2021
    cambios en las posiciones de los componentes y pistas
    [PCB SRCA.brd, PCB SRCA.sch]
2021-07-22 22/07/2021
    Se actualizo la pcb con todos los componentes y pistas, además se agregó las librerías del proyecto
    [PCB SRCA.brd, PCB SRCA.sch]
2021-08-12 11/08/2021
    cambios pre finales del pcb y sus componentes
    [PCB SRCA.brd, PCB SRCA.sch]
2021-08-13 12/08/2021
    correccion de sensor de temperatura
    [PCB SRCA.brd, PCB SRCA.sch]
2021-08-21 20/08/2021
    se adjunta los archivos de la PCB final con logo y archivo gerber
    [PCB SRCA.brd, PCB SRCA.sch]
2021-08-23 23-08-2021
    actualizaciones de nombres y logos
    [PCB SRCA.brd]
2021-08-24 23-08-2021
    pcb y cotización
    [PCB SRCA.brd, PCB SRCA.sch]
2021-08-24 24-08-2021
    correccion de errores en pistas
    [PCB SRCA.brd, PCB SRCA.sch]
2021-08-26 26-08-2021
    Actulizacion de la pcb correccion de pistas separacion entre ellas
    [PCB SRCA.brd, PCB SRCA.sch]
2021-09-01 31-08-2021
    se agregaron las librerías del proyecto se hizo algunas correciones en la parte de el sensor de temperatura y se hizo se coloco un regulador de 5V a 3.3V para la lora mote
    [PCB SRCA.brd, PCB SRCA.sch]
2021-09-01 31-08-2021
    imagenes del pcb
2021-09-01 31-08-2021
    se cargo las nuevas imágenes al readme y el modelo 3d
2021-09-01 01-09-2021
    readme para basar se en la construccion del protocolo
2021-09-05 04-09-2021
    cambios de la nueva pcb se agrego cambios del uart entre dspic y lora
    [PCB SRCA.brd, PCB SRCA.sch]
2021-09-06 06-09-2021
    se revirtio el cambio de el divisor de voltaje del lora al DSPIC
    [PCB SRCA.brd, PCB SRCA.sch]
2021-09-21 21-08-2021
    se adiciono la explicación del protocolo serial, aun falta agregar las funciones, se esta revisando un fallo especifico
2021-11-18 18-11-2021
    Copia de codigo de comunicacion avanzada de LoRa Mote a LoRa Mote
    1. aqui se encuentra la libreria Lora basica
    2. protocolo de comunicacion
2022-03-24 24-03-2022
    Se agregó la interfaz grafica
2022-03-25 25-03-2022
    actulización de veriones de librerias para los codigos
